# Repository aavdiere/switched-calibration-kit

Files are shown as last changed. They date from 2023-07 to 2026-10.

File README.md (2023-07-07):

# Switched Calibration Kit (SCal)
DIY calibration module that automatically switches between calibration standards.
The idea is to use of the shelf RF switches with simple SMD resistors, which can be characterized using a reference measurement of a VNA and then used as a standard.

This is a data based approach is bound to imperfections. The other way would be to make a model of the calibration kit and reference that instead of a measurement.
As it is quite difficult to create a model for the switches without knowing the exact layout, the data approach was preferred.
The SCal is characterised and measured on the same day to avoid temperature fluctuations as they will impact the validity of the reference measurement, temperature control should be added on future revisions.

The boards were manufactured using Aisler's [four layer boards](https://community.aisler.net/t/4-layer-hd-pcb-stackup/86) using the Panasonic Prepreg 1080 Type R-1551(W).
The traces were designed to be 50Ω according to Aisler's recommendations.

## First version - Simple, cheap, proof of concept
Calibration kit using Infineon BGS12PN10/BGS14PN10.
- 2 ports
- 50 Ohm path
- Open path
- Short path
- Through path
- 3dB attenuation path

## Board
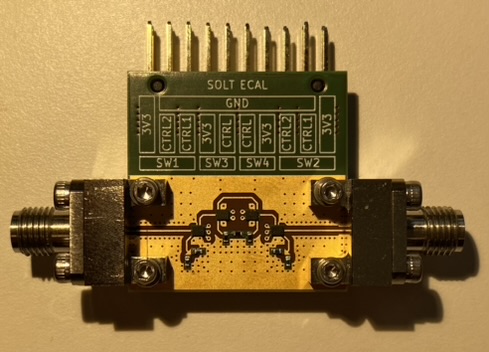
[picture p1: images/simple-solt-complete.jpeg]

*Full populated board. High-end K (2.92mm) connectors were used but are definitely not required. Screw on connectors were used to reduce the solder variability during initial measurements.*

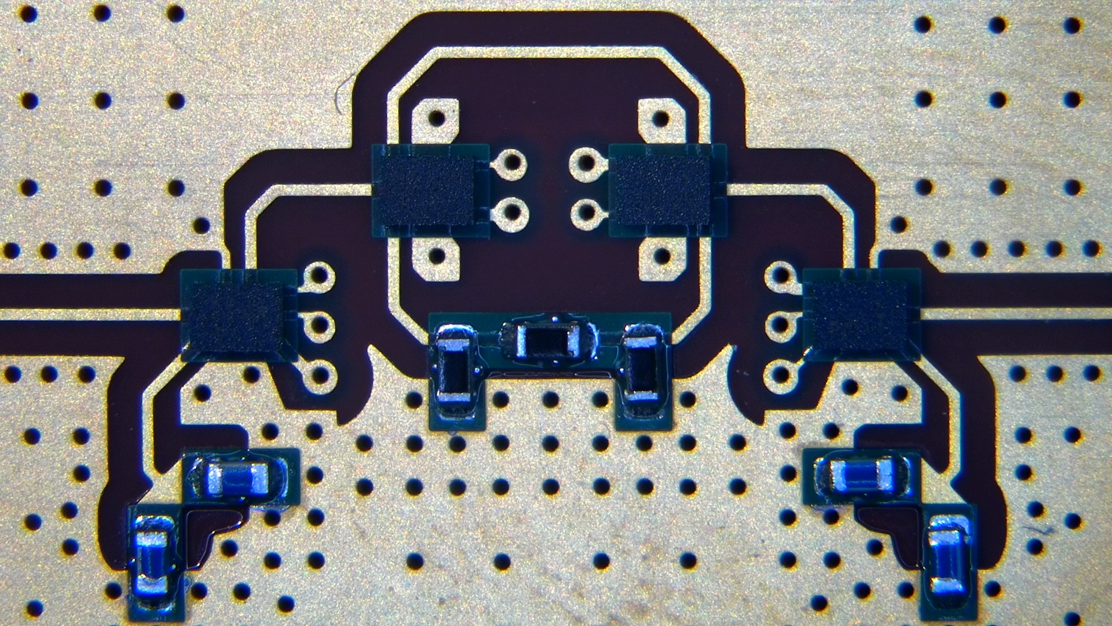
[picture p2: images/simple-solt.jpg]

*Close-up picture of the switches and standards. The 50Ω terminations are made using two paralell 100Ω resistors on the bottom left and right. The 3dB attenuator path can be seen in the middle, formed as a Π-network.*

## Measurement method
- Perform ECal using the Keysight N4691D calibration kit and the PNA-X
- Measure all of the standards of the custom ECal and save data with calibration applied (reference) and not applied
- Measure the Rosenberger RPC 2.92mm and save data with calibration applied (reference) and not applied
- Attach additional cable to existing cables
- Measure all of the standards of the custom ECal and save raw data (no calibration, raw)
- Measure the Rosenberger RPC 2.92mm and save raw data (no calibration, raw)
- Using Python and scikit-rf package, create a TwelveTerm network calibration using the measured reference ECal standards as ideals and the measured raw ECal standards as measured
- Use this error network to calibrate out the raw measurements of the Rosenberger calibration kit and compare them with the reference measurements

An additional measurement would be a repeatability test:
- Repeatedly measure short/open/load/through standards, making sure you unscrew and screw a different standard in and out each time
- Create the error network using all possible combinations of these measurements
- Measure the variance in error network parameters
- Do the same with the ECal (screw/unscrew after each run), the variance in parameters should be lower considering you don't need to unscrew/screw after measuring each standard

## Results
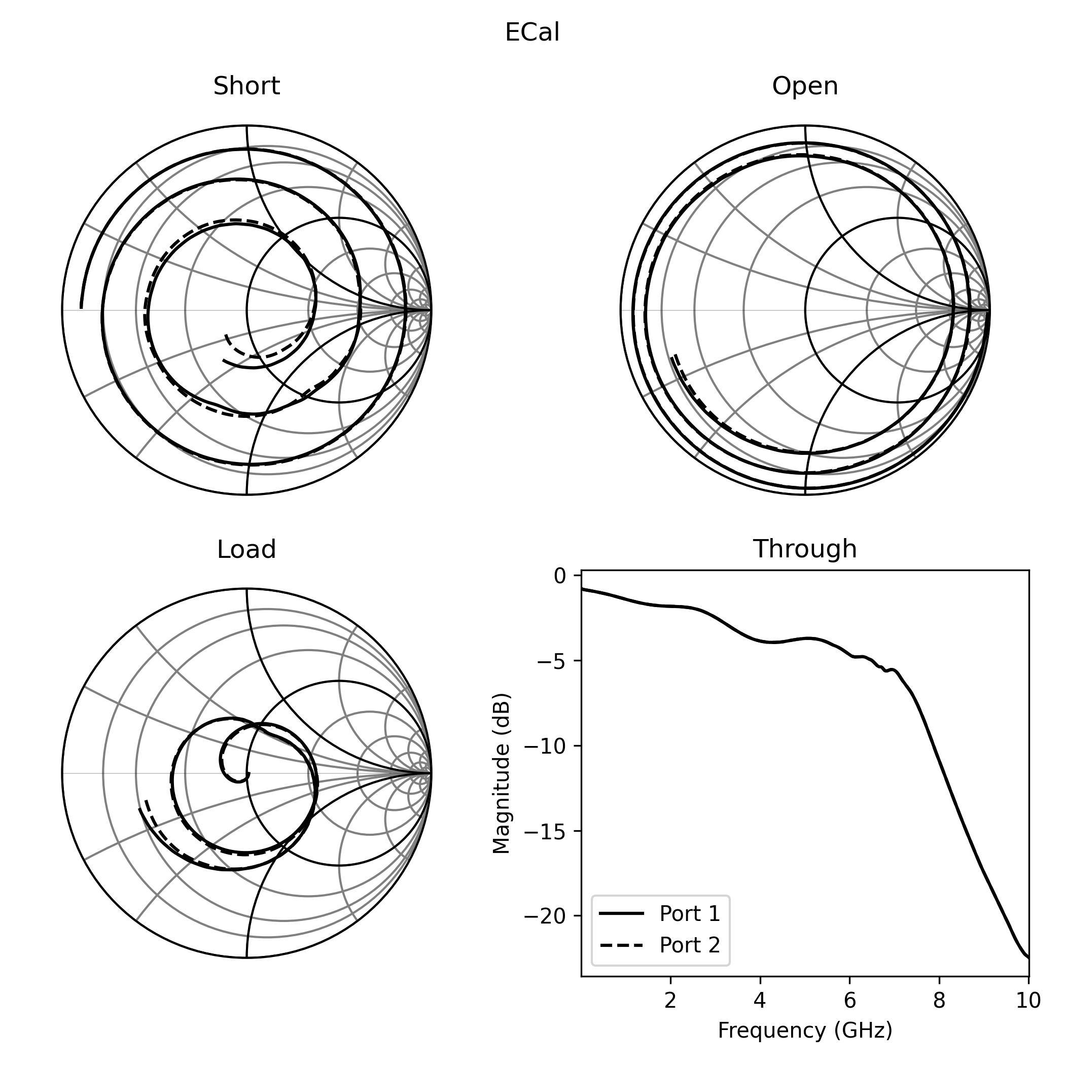
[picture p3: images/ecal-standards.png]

*Raw measurements of each of the standards. From the open and the short the port offset is visible as is the frequency dependent loss. The through result shows the bandwidth associated with the switches as well as the traces.*

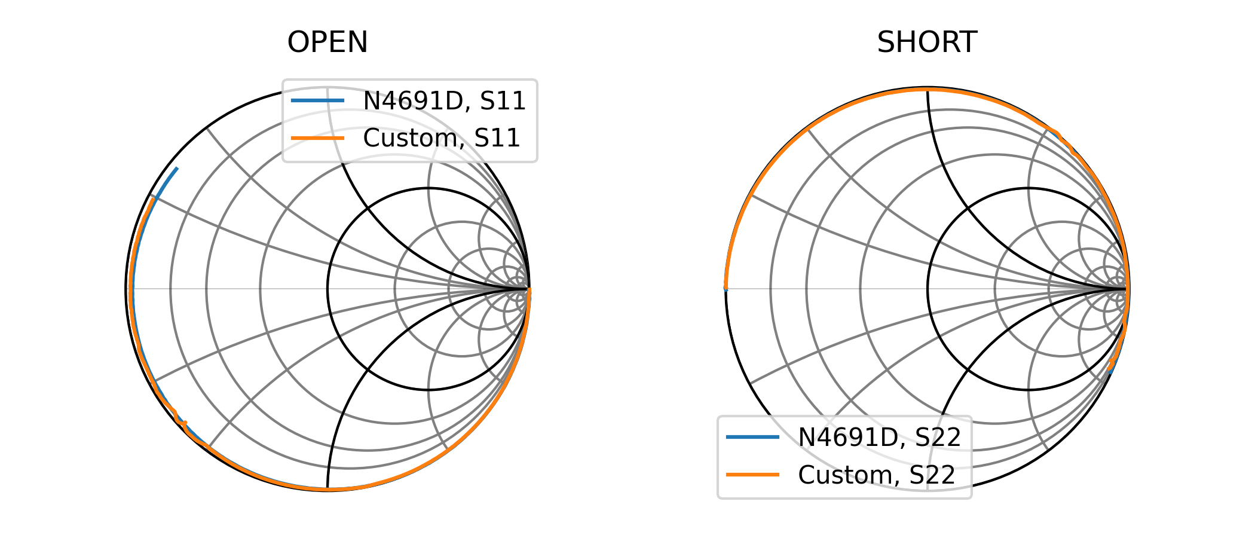
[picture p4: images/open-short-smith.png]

*Comparing the results from the SCal to the Keysight N4691D ECal, we can see comparible results, which look promising.*

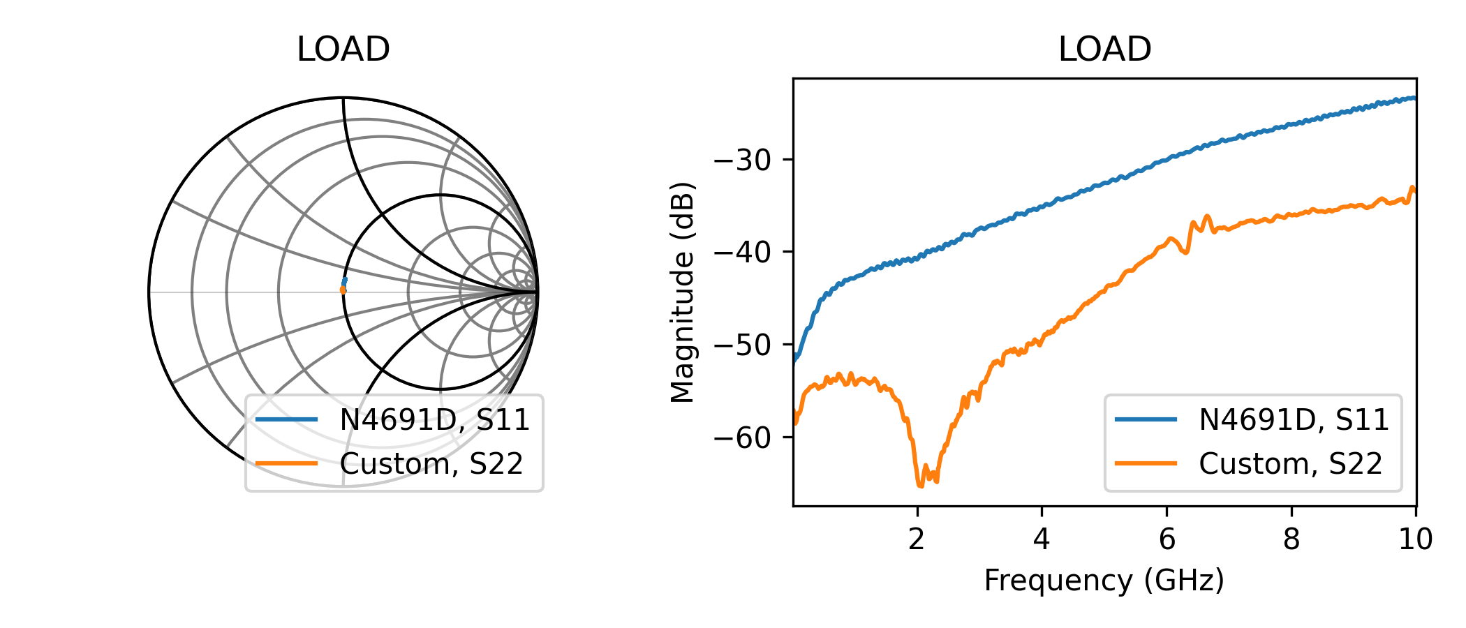
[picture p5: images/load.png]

*Differences in the measured load, somehow the SCal provides better results than the N4691D.*

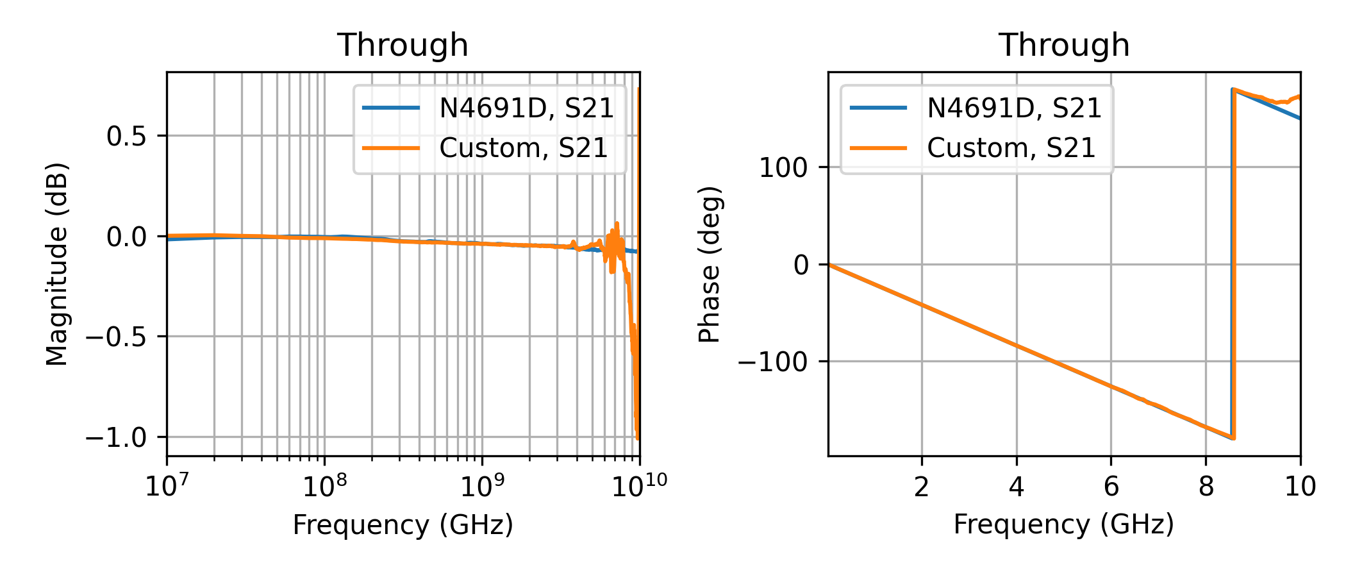
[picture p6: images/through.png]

*Here we can see the limitations of the measurements/switches. The measured through is nicely characterised up to around 3GHz, after which the SCal starts to deviate.*

## Remarks
The currently used silkscreen is confusing and prone to interconnection errors.
It might be a good idea to allow for rotational symmetry in the connector or to simply swap the legend around.

When looking at the load on the SCal, the S-parameters show that it starts of quite capacitive, which is odd.
This makes modelling it with typical methods difficult.
Maybe removing the whole top ground plane could fix that and only relying on microstrip lines.

The attenuator (not shown) doesn't have good performance, not even close.
Maybe using smaller resistors or a dedicated attenuator chip would be better.

The open and short standard should be located af far away from each other as possible as not to resonate.

The switches used have a minimum frequency in the datasheet.
This minimum frequency was ignored here and did not show up in the results.
However, if they are using PIN diodes to do the switching, the inductors used might not be good enough at lower frequencies, so watch out.

Overall the SCal has very nice results and could be usable for lower frequency measurements.

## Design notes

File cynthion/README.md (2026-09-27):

# Sniffing Keysight ECal USB interface using Cynthion

## Environment
To set-up the Python environment, you can use a version of conda.
```console
$ conda env create -f environment.yml
```

You can update a python environment from the [environment](environment.yml) file using
```console
$ conda env update -f environment.yml --prune
```

You can export conda environment to the [environment](environment.yml) file using
```console
$ conda export > environment.yml
```

## ECal states
https://documentation.help/SNP-M937xA/documentation.pdf

```python
set_state(device, 42)  # thru
set_state(device, 40)  # confidence
set_state(device, 36)  # open (a)
set_state(device, 33)  # open (b)
set_state(device, 39)  # short (a)
set_state(device, 45)  # short (b)
set_state(device, 37)  # load
set_state(device, 53)  # offset short
set_state(device, 5)  # impedance 5 (offset open)
set_state(device, 21)  # impedance 6 (offset short)
set_state(device, 38)  # impedance 7 (offset short)
```

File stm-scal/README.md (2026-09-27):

# STM Template

Template project tailored with use with STM32 microcontroller and Visual Studio Code.
The default is made for stm32l4 with JLink programmer and should be modified accordingly.

## Prerequisites

You need to have the following installed and properly setup. Ensure that they are available in your path.

- [GNU ARM Embedded tools](https://developer.arm.com/downloads/-/gnu-rm)
- [GNU Make](https://www.gnu.org/software/make/)
- Linker script for the MCU, probably has to be created manually, example can be found in the [libopencm3 example repository](https://github.com/libopencm3/libopencm3-examples)

### When using Visual Studio Code

You'll want to install some extensions to make development smoother

- `C/C++`
- `Cortex-Debug`
- `CMake Tools`

## Repo setup

Change the microcontroller identifier in the [Makefile](Makefile) and, when using Visual Studio Code, change it in [settings.json](.vscode/settings.json)

```bash
# Initialise the submodules (libopencm3)
git submodule init
git submodule update

# Build libopencm3
make -j8 -C vendor/libopencm3

# Build the main application firmware
make
```

## Debuggers

### J-Link

The YouTube series makes use of J-Link debugger hardware and JLinkGDBServer for integrating with VS Code's debug functionality.

You can use the "JLink: Debug Application" and "JLink: Attach to active" VSCode tasks to debug your built binaries.

### ST-Link

ST-Link is alternative debugger that you can use if you don't have a JLink debugger.

It's recommended that you install the [ST-Link drivers](https://www.st.com/en/development-tools/stsw-link009.html).

You'll also need to install the [open source ST-Link debugging tools](https://github.com/stlink-org/stlink). The primary application you'll need from that tool-set is *stutil*. Verify that *stutil* is available in your path before attempting to use the VSCode ST-Link debugging tasks.

Once your drivers and debugging tools are installed, you can use the "ST-Link: Debug Application" and "ST-Link: Attach active" VSCode tasks to debug your firmware over ST-Link.

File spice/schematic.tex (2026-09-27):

\documentclass[border=10pt]{standalone}
\usepackage[siunitx, americanvoltages, americancurrents]{circuitikz}
\ctikzset{resistors/scale=0.8, capacitors/scale=0.8}

\begin{document}
\begin{circuitikz}[scale=1.0, every node/.style={font=\footnotesize}]

% ================= Op-amp (declared first so its anchors can be used below) =================
\node[op amp] (opamp) at (6,7) {};

% ================= PI feedback rail (top row, y=11) =================
\draw (-2,11) to[V, l_=$V_{set}$=1.2V] ++(0,-1.8) node[ground]{};
\draw (-2,11) to[R, l=$R_{in}$=10k] (5,11) coordinate (nsum);
\draw (nsum) to[R, l=$R_{fb}$=100k] (7,11)
             to[C, l=$C_{int}$=3000$\mu$F] (8,11) coordinate (ngtop);
\draw (nsum) |- (opamp.-);

% ================= NTC sense divider =================
\draw (2,9.3) to[V, l=$V_{in}$=3.3V] (2,6.5) node[ground]{};
\draw (2,9.3) -- (2,9.6) -- (3.5,9.6)
      to[R, l=$R_s$=10k] (3.5,8);
\node[circ, label=right:$n_{temp}$] at (3.5,8) {};
\draw (3.5,8) to[R, l_=$R_{ntc}(T)$] (3.5,6.5) node[ground]{};
\draw (3.5,8) -- (4.5,8) |- (opamp.+);

% ================= Op-amp wiring =================
\draw (opamp.out) -- (8,7) coordinate (ngate);
\node[circ, label=below:$n_{gate}$] at (ngate) {};
\draw (opamp.up)   -- ++(0,0.4) node[above]{$n_{5v}$};
\draw (opamp.down) -- ++(0,-0.4) node[below]{GND};
\draw (ngtop) -- (ngate);

% ================= Heater switch =================
\draw (12,9.3) to[V, l=$V_{5v}$=5V] (12,7.4);
\node[circ] at (12,7.4) {};
\draw (12,7.4) -- (12.8,7.4);
\node[nmos] (M1) at (12.8,6.4) {};
\draw (12.8,7.4) -- (M1.D);
\draw (ngate) -- ++(0,-3.0) -| (M1.G);
\draw (M1.S) -- ++(0,-0.5) coordinate (nsrc);
\node[circ, label=right:$n_{source}$] at (nsrc) {};
\draw (nsrc) to[R, l_=$R_{heat}$=4$\Omega$] ++(0,-1.8) node[ground]{};

% ================= Thermal coupling (dashed) =================
\draw[dashed, ->, thick] (12.8,3.1) -- (12.8,0.8) -- (3.5,0.8) -- (3.5,6.3);
\node[font=\scriptsize, align=center] at (7,2.2)
      {thermal link: heater power $\to$ node ``temp'' (Celsius)\\
       $R_{th}$=8 C/W, $C_{th}$=39.9 J/C, ambient=22C\\
       $R_{ntc}$ value driven by resulting temp};

\end{circuitikz}
\end{document}

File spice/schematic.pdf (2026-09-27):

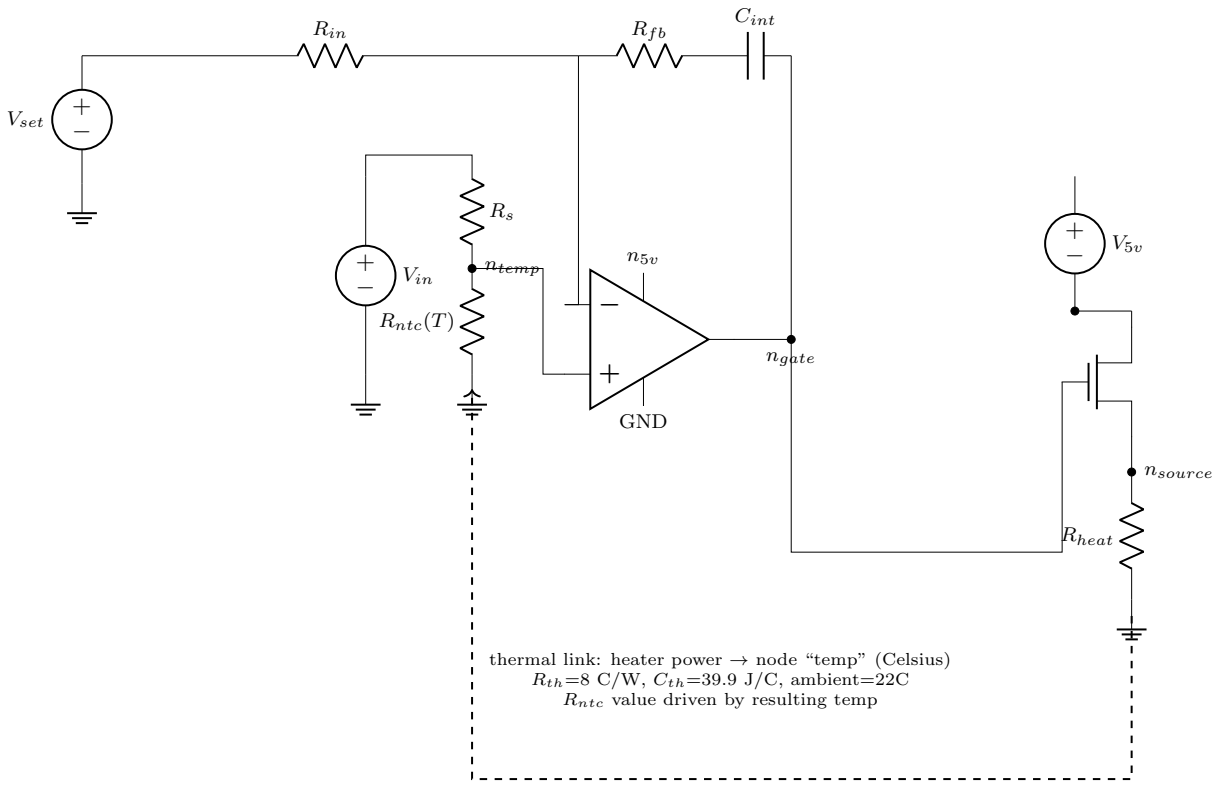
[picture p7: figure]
+ Vset; Rin; Cint; Vin; ntemp; Rntc(T); ngate; GND; nsource; Rheat; Rth=8 C/W, Cth=39.9 J/C, ambient=22C Rntc value driven by resulting temp

thermal link: heater power → node “temp” (Celsius)

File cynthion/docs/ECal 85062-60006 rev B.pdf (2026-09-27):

## ECal kit 85062-60006

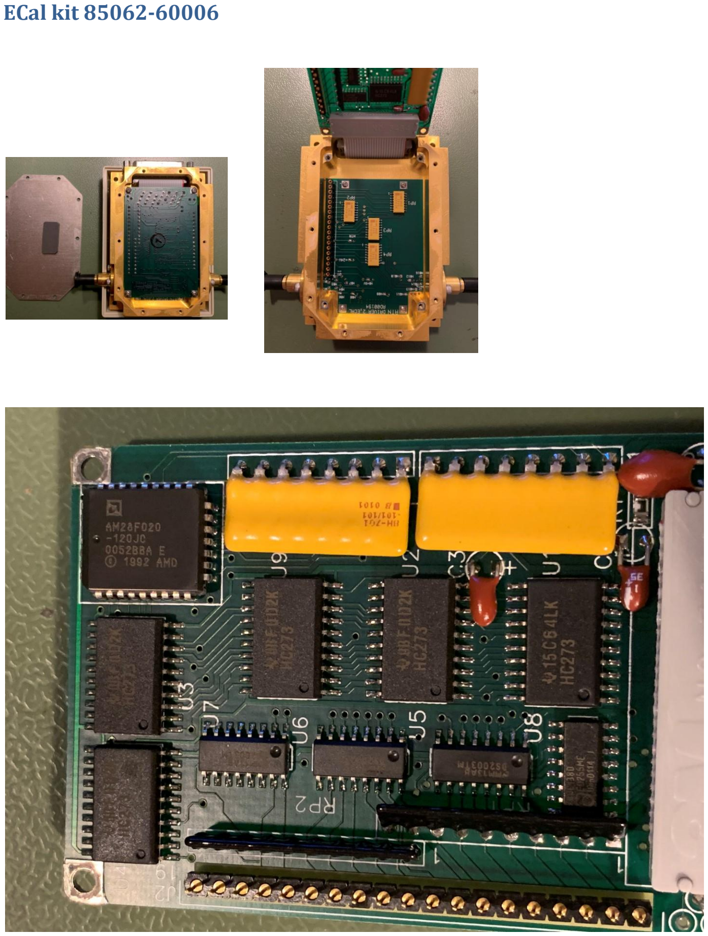
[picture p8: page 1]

## Pin connections DSUB-25

Table. Pinout DSUB-25 on 85062-6006 ECal kit. Last two columns not relevant for the kit, but can be used when building an Arduino adapter.

Pin | Input/Output (to/from 85062) | Description | Colour on cables | Arduino pin
1 | Power | J2-19, Analog +24 V *
14 | Power | J2-18, Analog GND***
2 | Power | Digital GND***, connected to DSUB-15
15 | Power | Digital GND***, connected to DSUB-2 | Black | GND
3 | Power | VCC +5 V*, U8-6 (Mux E3) | Red | +5 V
16 | Power | J2-17 Analog +5 V*
4 | I | Flash pin 1 VPP
17 | I | Analog -12 (negative) V* Jumper site 1 ****
5 | O | Short to DSUB-18 “Detect connect”
18 | O | Short to DSUB-5 “Detect connect”
6 | I | D-latch-1 MR’ = CLEAR’ | White | A2
19 | I | Flash-31 WE’ | Orange | A1
7 | I | Flash-24 OE’, HOLD HIGH when flash is not selected! | Orange | A0
20 | I | U8-4,5 E1’, E2’, Mux Enable | Green | D13
8 | I | U8-3 A2 Mux address | Green | D12
21 | I | U8-2 A1 Mux address | Green | D11
9 | I | U8-1 A0 Mux address | Green | D10
22 | I/O** | D-latch-D7, Flash-D7 | White | D9
10 | I/O** | D-latch-D6, Flash-D6 | White | D8
23 | I/O** | D-latch-D5, Flash-D5 | White | D7
11 | I/O** | D-latch-D4, Flash-D4 | White | D6
24 | I/O** | D-latch-D3, Flash-D3 | White | D5
12 | I/O** | D-latch-D2, Flash-D2 | White | D4
25 | I/O** | D-latch-D1, Flash-D1 | White | D3
13 | I/O** | D-latch-D0, Flash-D0 | White | D2
* Note. DSUB 1, 3, 16, 17. These are only fed from 85097 when DSUB-5 and -18 are connected to each other (max voltage drop 2 V, unloaded voltage drop between these pins is 12 V).

**Note. To protect from driving a pin that may be configured for output, a 10 kΩ resistor can be put in series without affecting function.

***Note. Digital and analog GND should be connected externally as they are so in the controller 85097. Otherwise current for Analog 5 V will not be able to flow properly.

****Note. On the board where the DSUB is connected, there is a ‘jumper site’ – small area with three holes labeled 1, 2 and 3. In this unit, 2 and 3 connected, 1 not connected. This site appears to be used for passing -12 V in (at least) low frequency units.

## Chips

### U8 – 74HC138 3-8 MUX

### U1, U2, U9, U3, U4 – 74HC238 D-latch. All sharing D0-D7 and MR’ connected to DSUB-6

U5, U6, U7 DS2003, Darlington drivers ending up in J2. Fed by D-latches.

### Flash AM28F020, 8 MBit Flash, 256kx8

U8 MUX connection to other ICs. Chosen address sets corresponding pin LOW when U8 is enabled

### (otherwise all pins are HIGH)

MUX Address | IC
0 | U1 D-Latch (Clock pos edge) -> U5:1-7, U6:1 -> J2:1-8
1 | U2 D-Latch (Clock pos edge) -> U6:2-7, U7:1-2 -> J2:9-16
2 | U3 D-Latch (Clock pos edge) Flash A0-A7
3 | U4 D-Latch (Clock pos edge) Flash A8-A15
4 | U9 D-Latch (Clock pos edge) Flash A16-A17 (Q2 – Q7 unused)
5
6
7 | Flash-22 – CE’

## D-Latch

WRITING to D-Latch is done by selecting one chip (this clock pin goes low), activate data bus and deselect the chip (clock pin goes high). Thus, writing to D-latches occurs when deselecting the chip!

## Sequence to RESET ALL D-Latches:

DSUB20 HIGH | U8-4,5 E1’, E2’ (mux disabled, all pins high)
DSUB6 LOW | All D-Latch CLR’ activated
DSUB6 HIGH | All D-Latch CLR’ deactivated

## Sequence to write certain D-Latch:

DSUB6 HIGH | All D-Latch CLR’ deactivated
DSUB20 HIGH | U8-4,5 E1’, E2’ (MUX disabled, all pins high)

### DSUB 9/21/8 ADDRESS U8 A0-A2, select MUX pin address

DSUB20 LOW | U8-4,5 E1’, E2’ (MUX enabled, addressed pin low)
DSUB D-Latch D0-D7 | DATA set data on pins 22, 10, 23, 11, 24, 12, 25, 13
DSUB20 HIGH | U8-4,5 E1’, E2’ (MUX disabled, all pins high, DATA is clocked into D-Latch)

## Flash

Flash CE’ is active low and will thus activate when selected.

### CAUTION: When activated, it MAY OUTPUT VOLTAGE ON DSUB D-Latch D0-D7/Flash D0-D7! Thus

use a series 10 kΩ resistor on each line.

Flash: CE’ – controls power within the device. Keep low.

Flash: OE’ – Output enable if pin is LOW. If pin is high, data pins are three state! Set this pin HIGH

### when programming D-Latches!

With OE’ LOW, Flash will output the data stored in location specified by address stored in U3, U4 and U9

WE’ should be held HIGH, but likely not an issue as long as VPP isn’t pulled too high...

## Pins on J2 (controlling RF circuitry)

Programming pins on J2 1-16. Setting one of the bits in the D-Latch registers HIGH will pull the corresponding J2 pin set (LOW). Voltage on J2 pins are approx 4.5 V when set (LOW) and 21.8 when not set (HIGH). Current consumption on 24 V seems not affected by the pins being HIGH or LOW.

On 5 V, current draw is depending on any bit being high or not. For all bits 0, current draw is 0, any bit set, current draw is approx 340 uA if GNDs are connected by 10 kOhms.

## Current draw

Note that 24 V seems to draw substantial amounts of current. This is related to the internal heater of the ECal kit. By setting current limit to 300 mA, it takes approximately 30 minutes to reach a steady state where current decreases to approximately 80 mA.

The +5 V analog draws approximately 40 mA per activated switch (i. e, some 120 mA in normal configuration like 0x8003, 0x4003 etc).

### More thorough data from W. Knowles:

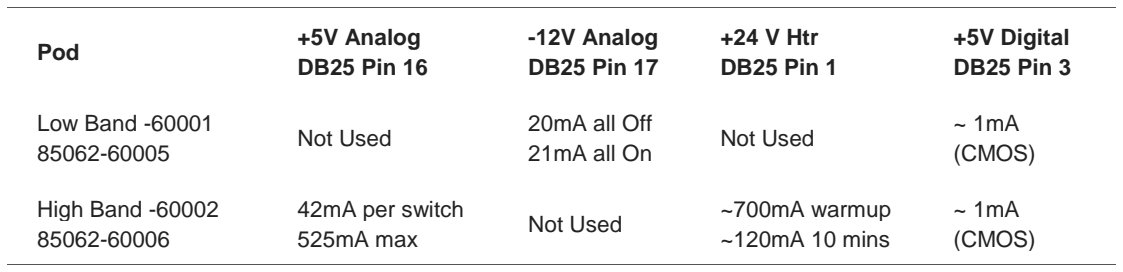
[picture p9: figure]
Pod; +5V Analog; DB25 Pin 16; -12V Analog DB25 Pin 17; +24 V Htr DB25 Pin 1; +5V Digital DB25 Pin 3; Low Band -60001; Not Used; 20mA all Off; 21mA all On; (CMOS); High Band -60002 85062-60006; 42mA per switch; 525mA max; ~700mA warmup; ~120mA 10 mins; ~ 1mA (CMOS)

## Flash content HP85062-60006 ECAL kit

0x0000 – 0x0063 Original info
0x0064 – | Serial no
0x0070 - | connector info
0x0084 - | possible update info, including cal site?
0x00B8 – | Revision?
0x00CC – | start and stop frequency as doubles
| 0x41cd cd65 0000 0000 –> 1 000 000 000
| 0x4218 ae17 a400 0000 –> 26 500 000 000
0x00DC – 0001 -> 256, number of points? 0x00DE – 2C01 -> 300, warm up time in seconds?
0x00E0 – | Frequency step as double
| 0x4197 d784 0000 0000 -> 100 000 000
0x00E8 – | Address 0x0001 8000?
0x00EC – 5595 -> 38229, number of bytes for all datasets?
0x00F0 – | Part no.
00000000: 4850 3835 3036 3043 2045 4341 4c00 85c0 | HP85060C ECAL...
00000010: 7c25 e87f 6400 4e6f 7620 3238 2031 3939 | |%..d.Nov 28 199
00000020: 3400 ffff ffff ffff ffff ffff ffff ffff | 4 |
00000030: ffff ffff ffff ffff ffff ffff ffff ffff | |
00000040: ffff ffff ffff ffff ffff ffff ffff ffff | |
00000050: ffff ffff ffff ffff ffff ffff ffff ffff | |
00000060: ffff ffff | 3031 3233 3400 31c0 50e8 8808 | ....01234.1.P...
00000070: | 3335 4633 3546 204d 5731 | 00c4 0456 e8fb | 35F35F MW1...V..
00000080: 0883 c402 | 3137 204d 6179 2032 3031 3100 | ....17 May 2011.
00000090: | 4147 494c 454e 542f 4d54 4100 b8f8 6aeb | AGILENT/MTA...j.
000000a0: 9383 3e94 0600 741e a182 0683 c041 a298 | ..>...t......A..
000000b0: 06c6 069b 0600 b804 | 3031 2e30 3000 | 00c6 | ........01.00...
000000c0: 08eb 29e9 9a00 8dbe 4cff 837e | 0000 0000 | ..).....L..~....
000000d0: | 65cd cd41 | 0000 00a4 17ae 1842 | 0001 2c01 | e..A.......B..,.
000000e0: | 0000 0000 84d7 9741 | 0080 0100 | 5595 0000 | .......A....U...
000000f0: | 3835 3036 322d 3630 3030 3600 | 0075 03e9 | 85062-60006..u..
00000100: 39ff c706 0000 0002 3130 3838 00e5 33c7 | 9.......1088..3.
00000110: 0686 0601 ffff ffff ffff ffff ffff ffff | |
00000120: ffff ffff ffff ffff ffff ffff ffff ffff | |
00000130: ffff ffff ffff ffff ffff ffff ffff ffff | |
00000140: ffff ffff ffff ffff ffff ffff ffff ffff | |
00000150: ffff ffff ffff ffff ffff ffff ffff ffff | |
00000160: ffff ffff ffff ffff ffff ffff ffff ffff | |
00000170: ffff ffff ffff ffff ffff ffff ffff ffff | |
00000180: ffff ffff ffff ffff ffff ffff ffff ffff | |

0x0190 – 0x1CD Header info for cal files.

Static structure beginning with one frequency list and then datasets of S-parameters. Prior to each set of S-parameters is a list of Short (16 bit) words about how the ECal shall be configured – see below.
Header content:

Frequency: No of entries (Short), start location (Long)

Corr values: No of config words for Ecal (Short), No of entries per set (short), No of sets (short), Start location config (Long), Start location first data set (Long)

00000190: 0001 f401 0000 0d00 0001 0d00 f409 0000 | |
000001a0: 0e0a 0000 0d00 0001 0d00 0e72 0000 2872 | | r..(r
000001b0: 0000 0100 0001 0400 28da 0000 2ada 0000 | ........(...*...
000001c0: 0100 0001 0400 2afa 0000 2cfa 0000 ffff | ......*...,.....
000001d0: ffff ffff ffff ffff ffff ffff ffff ffff | |
000001e0: ffff ffff ffff ffff ffff ffff ffff ffff | |

Frequency.
Frequency data starts at 0x000001F4 and contains 0x0100 entries. Data for frequency is stored in Double format (64 bit) in Hz. In this case, frequencies at 1.0, 1.1, ..., 26.5 GHz
000001f0: ffff ffff 0000 0000 65cd cd41 0000 00c0 | ........e..A....
00000200: 2a64 d041 0000 0000 a3e1 d141 0000 0040 | *d.A.......A...@

Corr values.
Following in the header are four areas of datasets (all containing more than one set of S-parameters). Config list contains Short (16 bit) config words to set the ECal to. Data is stored as Real, Imag, Real, Imag,... where each value is stored as float (32 bit)
No of config | Set length | No of sets | Config start | Set start
0x0D | 0x100 | 0x0D | 000009F4 | 00000A0E
0x0D | 0x100 | 0x0D | 0000720E | 00007228
0x01 | 0x100 | 0x04 | 0000DA28 | 0000DA2A
0x01 | 0x100 | 0x04 | 0000FA2A | 0000FA2C

### Dataset 1 0x09F4

13 config words, 13 datasets. One S-parameter per config.
Config # | Setting | Config # | Setting
0 | 8003 | 7 | 0083
1 | 4003 | 8 | 0043
2 | 2003 | 9 | 0023
3 | 1003 | 10 | 0013
4 | 0803 | 11 | 000B
5 | 0403 | 12 | 0007
6 | 0103

000009f0: 17ae 1842 0380 0340 0320 0310 0308 0304 | ...B...@. ......
00000a00: 0301 8300 4300 2300 1300 0b00 0700 0078 | ....C.#........x
00000a10: d2be 004c 533f 0014 8bbe 0054 613f 0050 | ...LS?.....Ta?.P
00000a20: 04be 0030 693f 0000 513c 0026 6b3f 0040 | ...0i?..Q<.&k?.@
00000a30: 1b3e 0080 673f 00d0 903e 00ba 5e3f 0074 | .>..g?...>..^?.t
00000a40: d03e 00a0 513f 0080 053f 000c 403f 00be | .>..Q?...?..@?..
00000a50: 1f3f 009e 2a3f 0066 363f 00f0 113f 0068 | .?..*?.f6?...?.h

### Dataset 2 0x720E

13 config words, 13 datasets. One S-parameter per config.
Config # | Setting | Config # | Setting
0 | C001 | 7 | C100
1 | C002 | 8 | C200
2 | C004 | 9 | C400
3 | C008 | 10 | C800
4 | C010 | 11 | D000
5 | C020 | 12 | E000
6 | C080
00007200: c93e 0008 d5bd 0088 af3e 00d8 76be 01c0 | .>.......>..v...
00007210: 02c0 04c0 08c0 10c0 20c0 80c0 00c1 00c2 | |
00007220: 00c4 00c8 00d0 00e0 0014 d0be 00de 543f

### Dataset 3 0xDA28

Single config, 4 datasets (all four S-parameters). DA28: 0x0000

0000da20: 00b2 b03e 0058 6ebe 0000 0070 943d 0018 | ...>.Xn....p.=..
0000da30: 3fbe 00c0 783c 00be 44be 0078 17bd 003e | ?...x<..D..x...>

### Dataset 4 0xFA2A

Single config, 4 datasets (all four S-parameters).
FA2A: 0x0200
0000fa20: a6bd 00fc 4d3d 00f6 b1bd 0002 000c 9c3e | ....M=.........>
0000fa30: 00bc 533f 0094 fc3e 00b6 3a3f 004c 263f | ..S?...>..:?.L&?

Length of the datasets (note: first location is also used for data): A0E – 720D : 26624, 13*256*2*4 = 26624...
722A – DA27: 26624...
DA2C – FA29: 8192
Finally:
0xFA2B + 0x2000 = 112AB. Data content in flash ends at 0x112AB.

### Useful or comments? Please drop me a line at testjarfalla63@gmail.com

### /Staffan

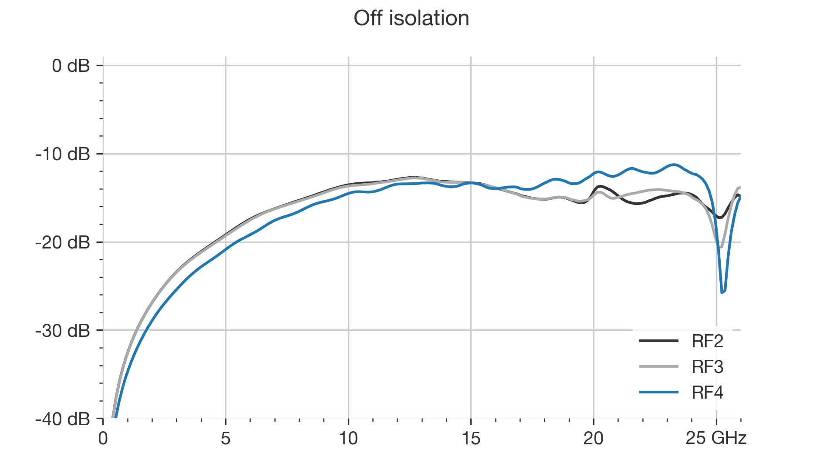
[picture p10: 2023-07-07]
images/off-isolation.png

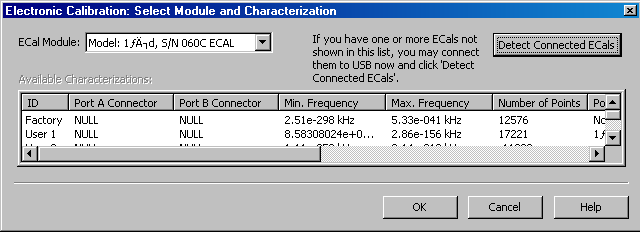
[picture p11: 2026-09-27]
cynthion/docs/Reverse-engineering a VNA ECal Interface With Cynthion - Great Scott Gadgets_files/ecal-garbled.png

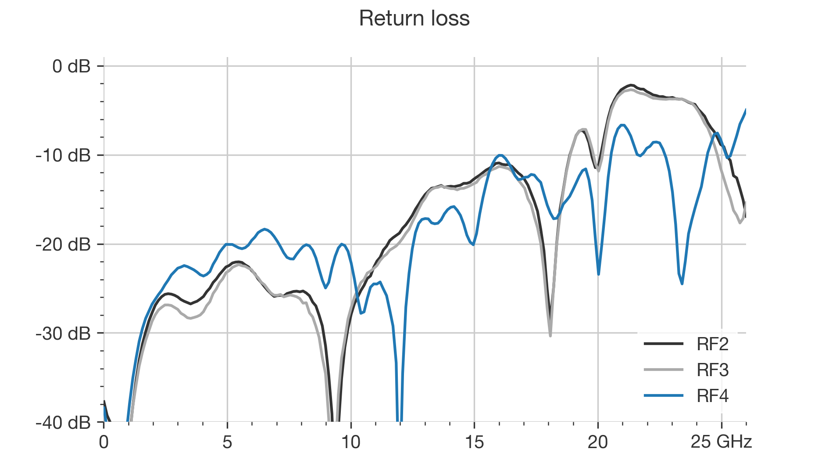
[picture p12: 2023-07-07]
images/return-loss.png

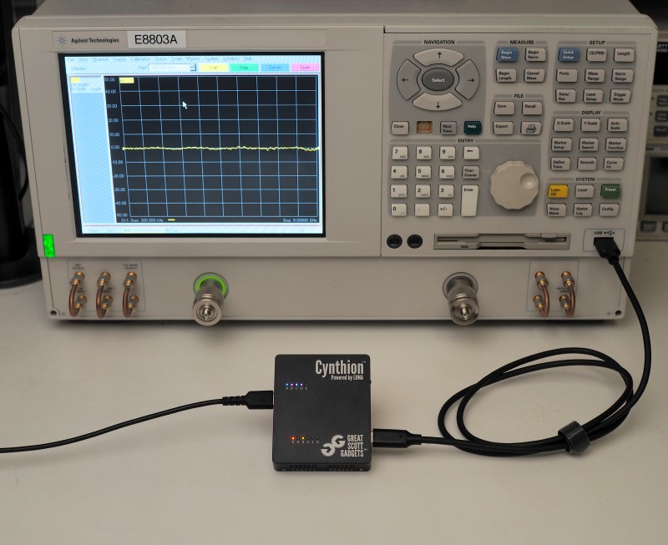
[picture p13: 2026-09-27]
cynthion/docs/Reverse-engineering a VNA ECal Interface With Cynthion - Great Scott Gadgets_files/ecal-vna.jpg

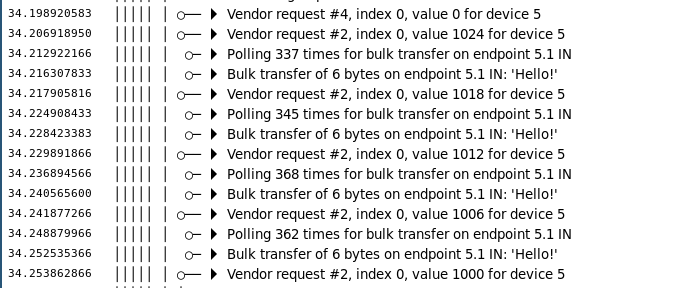
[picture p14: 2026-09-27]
cynthion/docs/Reverse-engineering a VNA ECal Interface With Cynthion - Great Scott Gadgets_files/ecal-packets.png

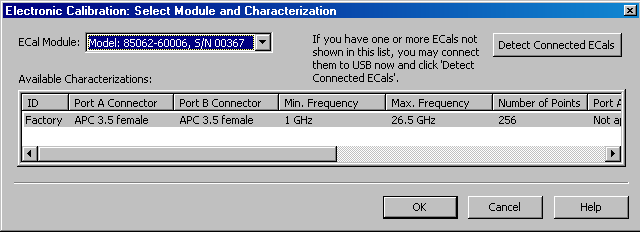
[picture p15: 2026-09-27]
cynthion/docs/Reverse-engineering a VNA ECal Interface With Cynthion - Great Scott Gadgets_files/ecal-correct.png

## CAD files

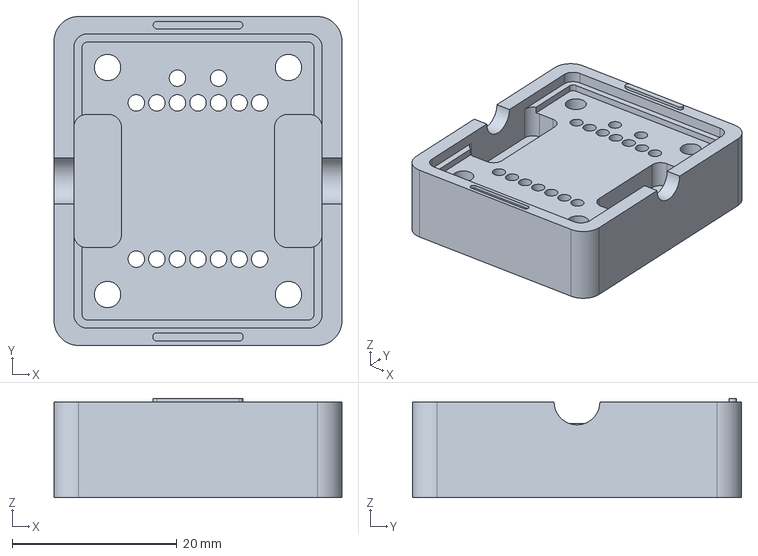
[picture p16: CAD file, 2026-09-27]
CAD/assembly-Assemblycase_bottom.step
35.0 x 40.0 x 12.1 mm

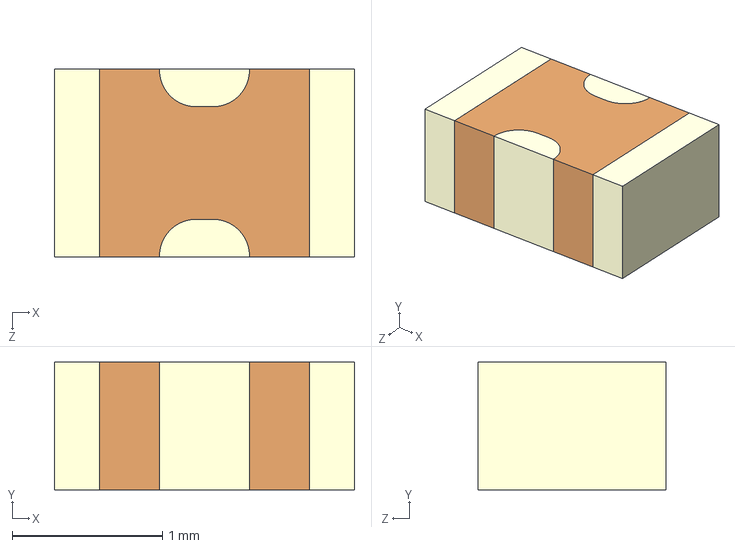
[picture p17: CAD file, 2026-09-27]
KiCad/ecal_controller/NFM21PC104R1E3D.stp
2.00 x 0.85 x 1.25 mm

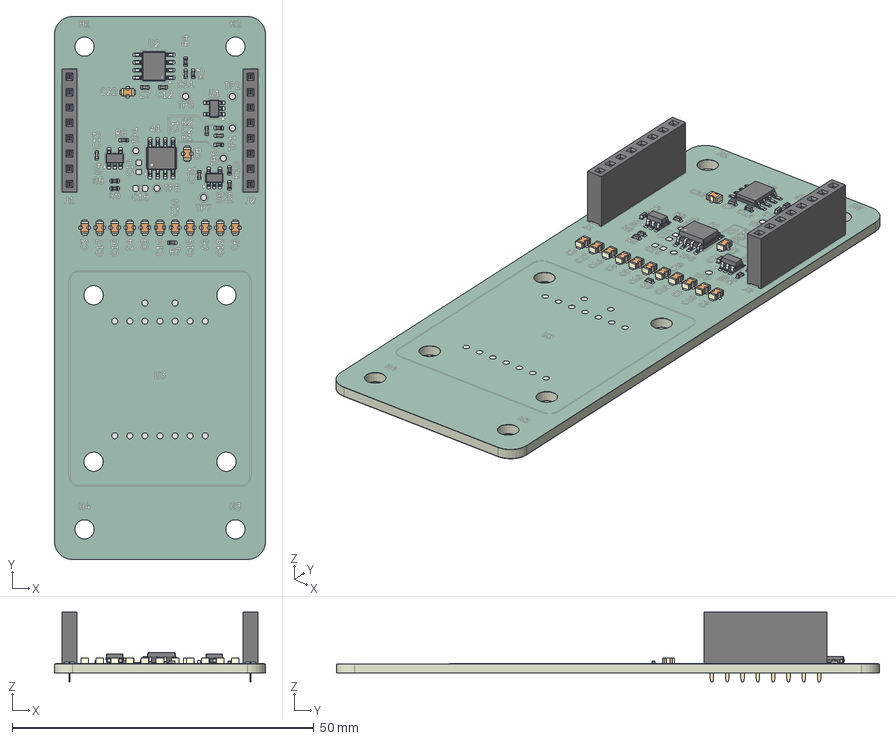
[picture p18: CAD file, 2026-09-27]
KiCad/ecal_heater_control/ecal_heater_control.step
35.0 x 90.0 x 11.6 mm
SOT-23-5 x 3
HTSOP-8-1EP_3.9x4.9mm_P1.27mm_EP2.4x3.2mm
R_0402_1005Metric x 10
NFM21PC104R1E3D x 13
SOIC-8_3.9x4.9mm_P1.27mm
C_0402_1005Metric x 7
PinSocket_1x08_P2.54mm_Vertical x 2
ecal_heater_control_copper
ecal_heater_control_pad
ecal_heater_control_via
ecal_heater_control_silkscreen
ecal_heater_control_soldermask x 2
ecal_heater_control_PCB

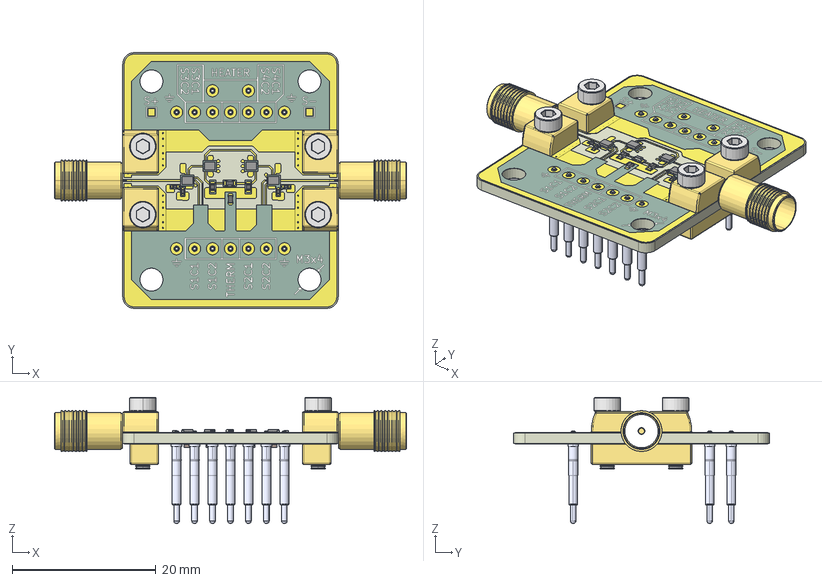
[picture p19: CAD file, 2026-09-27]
KiCad/ecal_simple_solt/ecal_simple_solt.step
49.0 x 35.6 x 17.6 mm
All x 2
R_0402_1005Metric x 4
BGS14PN10E6327XTSA1 x 4
R_0201_0603Metric x 4
C_0402_1005Metric x 4
Same_Sky_CPG-01-TH-B x 16
ecal_simple_solt_copper
ecal_simple_solt_silkscreen x 2
ecal_simple_solt_soldermask x 2
ecal_simple_solt_PCB

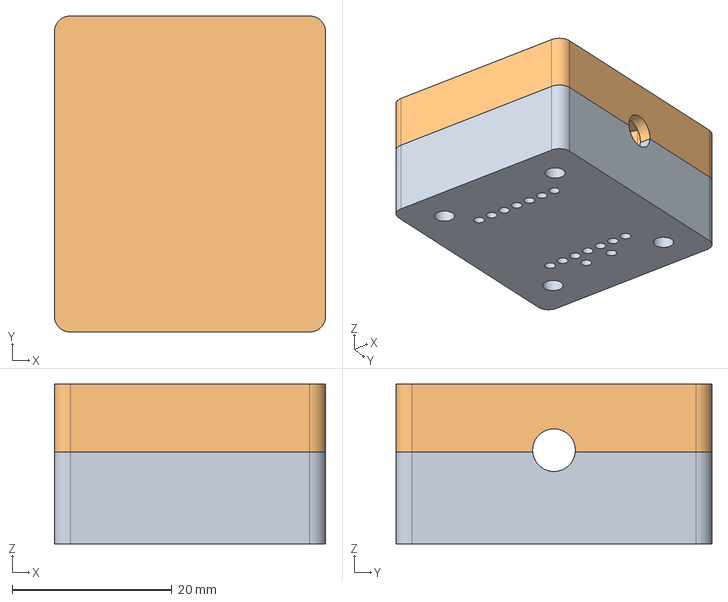
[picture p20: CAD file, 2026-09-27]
CAD/PCB.FCStd
34.0 x 39.6 x 20.0 mm
bottom
top

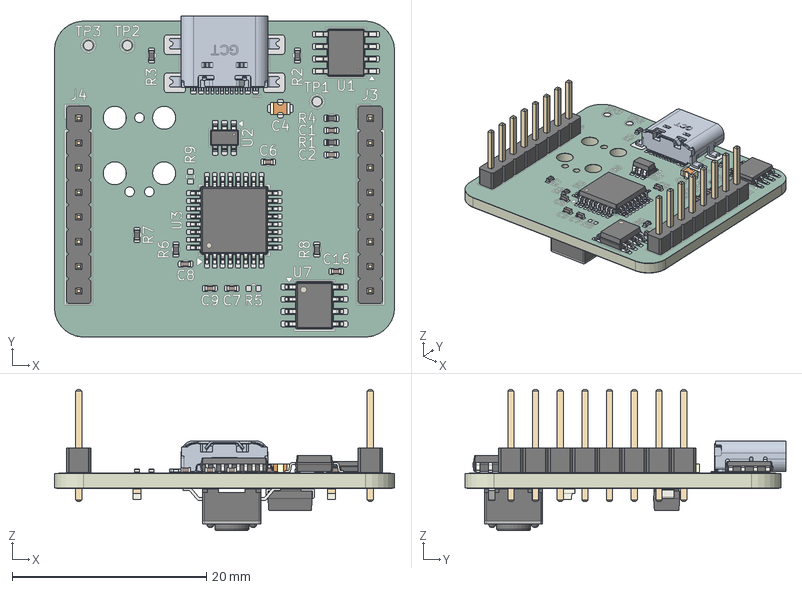
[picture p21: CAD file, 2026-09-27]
KiCad/ecal_controller/ecal_controller.step
35.0 x 33.0 x 14.5 mm
C_0402_1005Metric x 7
R_0402_1005Metric x 7
PinHeader_1x08_P254mm_Vertical x 2
SOT-23-6
LQFP-32_7x7mm_P0.8mm
HTSOP-8-1EP_3.9x4.9mm_P1.27mm_EP2.4x3.2mm
SOIC-8_3.9x4.9mm_P1.27mm
NFM21PC104R1E3D
SW_Push_1P1T_NO_E-Switch_TL3301NxxxxxG
LED_0603_1608Metric x 2
D_SMA
ecal_controller_copper
ecal_controller_pad
ecal_controller_via
ecal_controller_silkscreen x 2
ecal_controller_soldermask x 2
ecal_controller_PCB

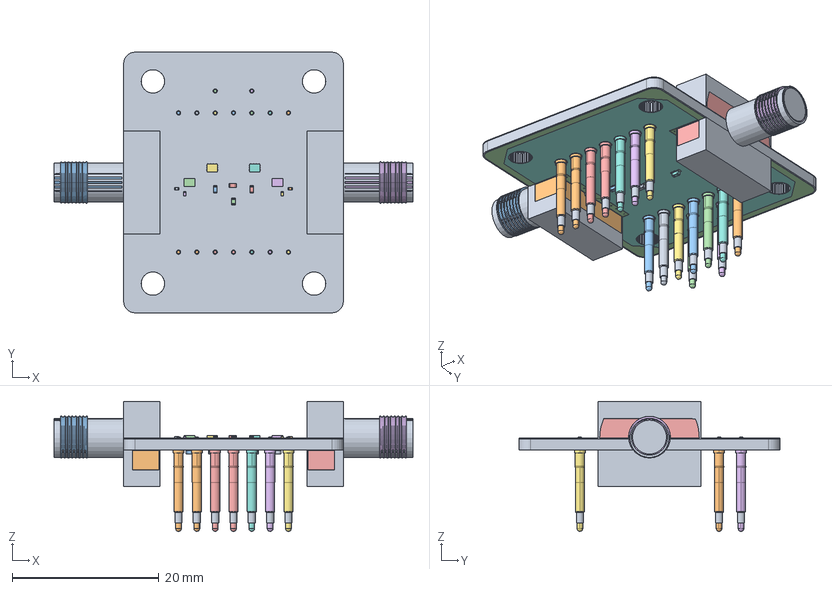
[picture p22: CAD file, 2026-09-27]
CAD/scal.FCStd
49.0 x 35.6 x 17.8 mm
abstract
All
All001
R_0402_1005Metric
R_0402_1005Metric002
BGS14PN10E6327XTSA1
BGS14PN10E6327XTSA001
BGS14PN10E6327XTSA002
R_0201_0603Metric
R_0201_0603Metric002
R_0402_1005Metric004
BGS14PN10E6327XTSA003
R_0402_1005Metric006
R_0201_0603Metric004
R_0201_0603Metric006
C_0402_1005Metric
Same_Sky_CPG-01-TH-B
Same_Sky_CPG-01-TH-B001
C_0402_1005Metric002
Same_Sky_CPG-01-TH-B002
Same_Sky_CPG-01-TH-B003
Same_Sky_CPG-01-TH-B004
Same_Sky_CPG-01-TH-B005
Same_Sky_CPG-01-TH-B006
C_0402_1005Metric004
Same_Sky_CPG-01-TH-B007
Same_Sky_CPG-01-TH-B008
Same_Sky_CPG-01-TH-B009
Same_Sky_CPG-01-TH-B010
Same_Sky_CPG-01-TH-B011
Same_Sky_CPG-01-TH-B012
Same_Sky_CPG-01-TH-B013
C_0402_1005Metric006
Same_Sky_CPG-01-TH-B014
Same_Sky_CPG-01-TH-B015
ecal_simple_solt_copper
ecal_simple_solt_silkscreen
ecal_simple_solt_silkscreen001
ecal_simple_solt_soldermask
ecal_simple_solt_soldermask001
ecal_simple_solt_PCB

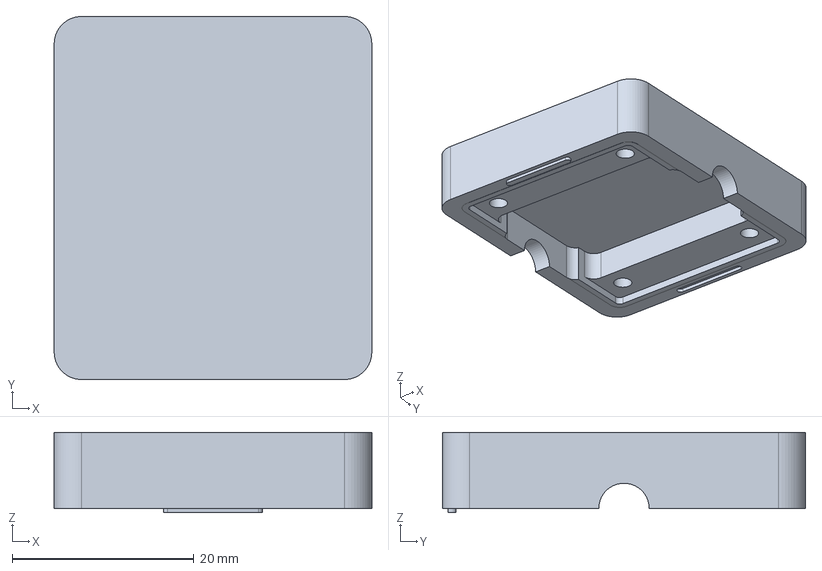
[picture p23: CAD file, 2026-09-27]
CAD/case-top.FCStd
35.0 x 40.0 x 8.82 mm

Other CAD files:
CAD/Assembly.FCStd
CAD/case.FCStd
CAD/case-bottom.FCStd
CAD/PCB.3mf
CAD/assembly-Assemblycase_bottom.3mf
CAD/assembly.FCStd
CAD/scal.3mf

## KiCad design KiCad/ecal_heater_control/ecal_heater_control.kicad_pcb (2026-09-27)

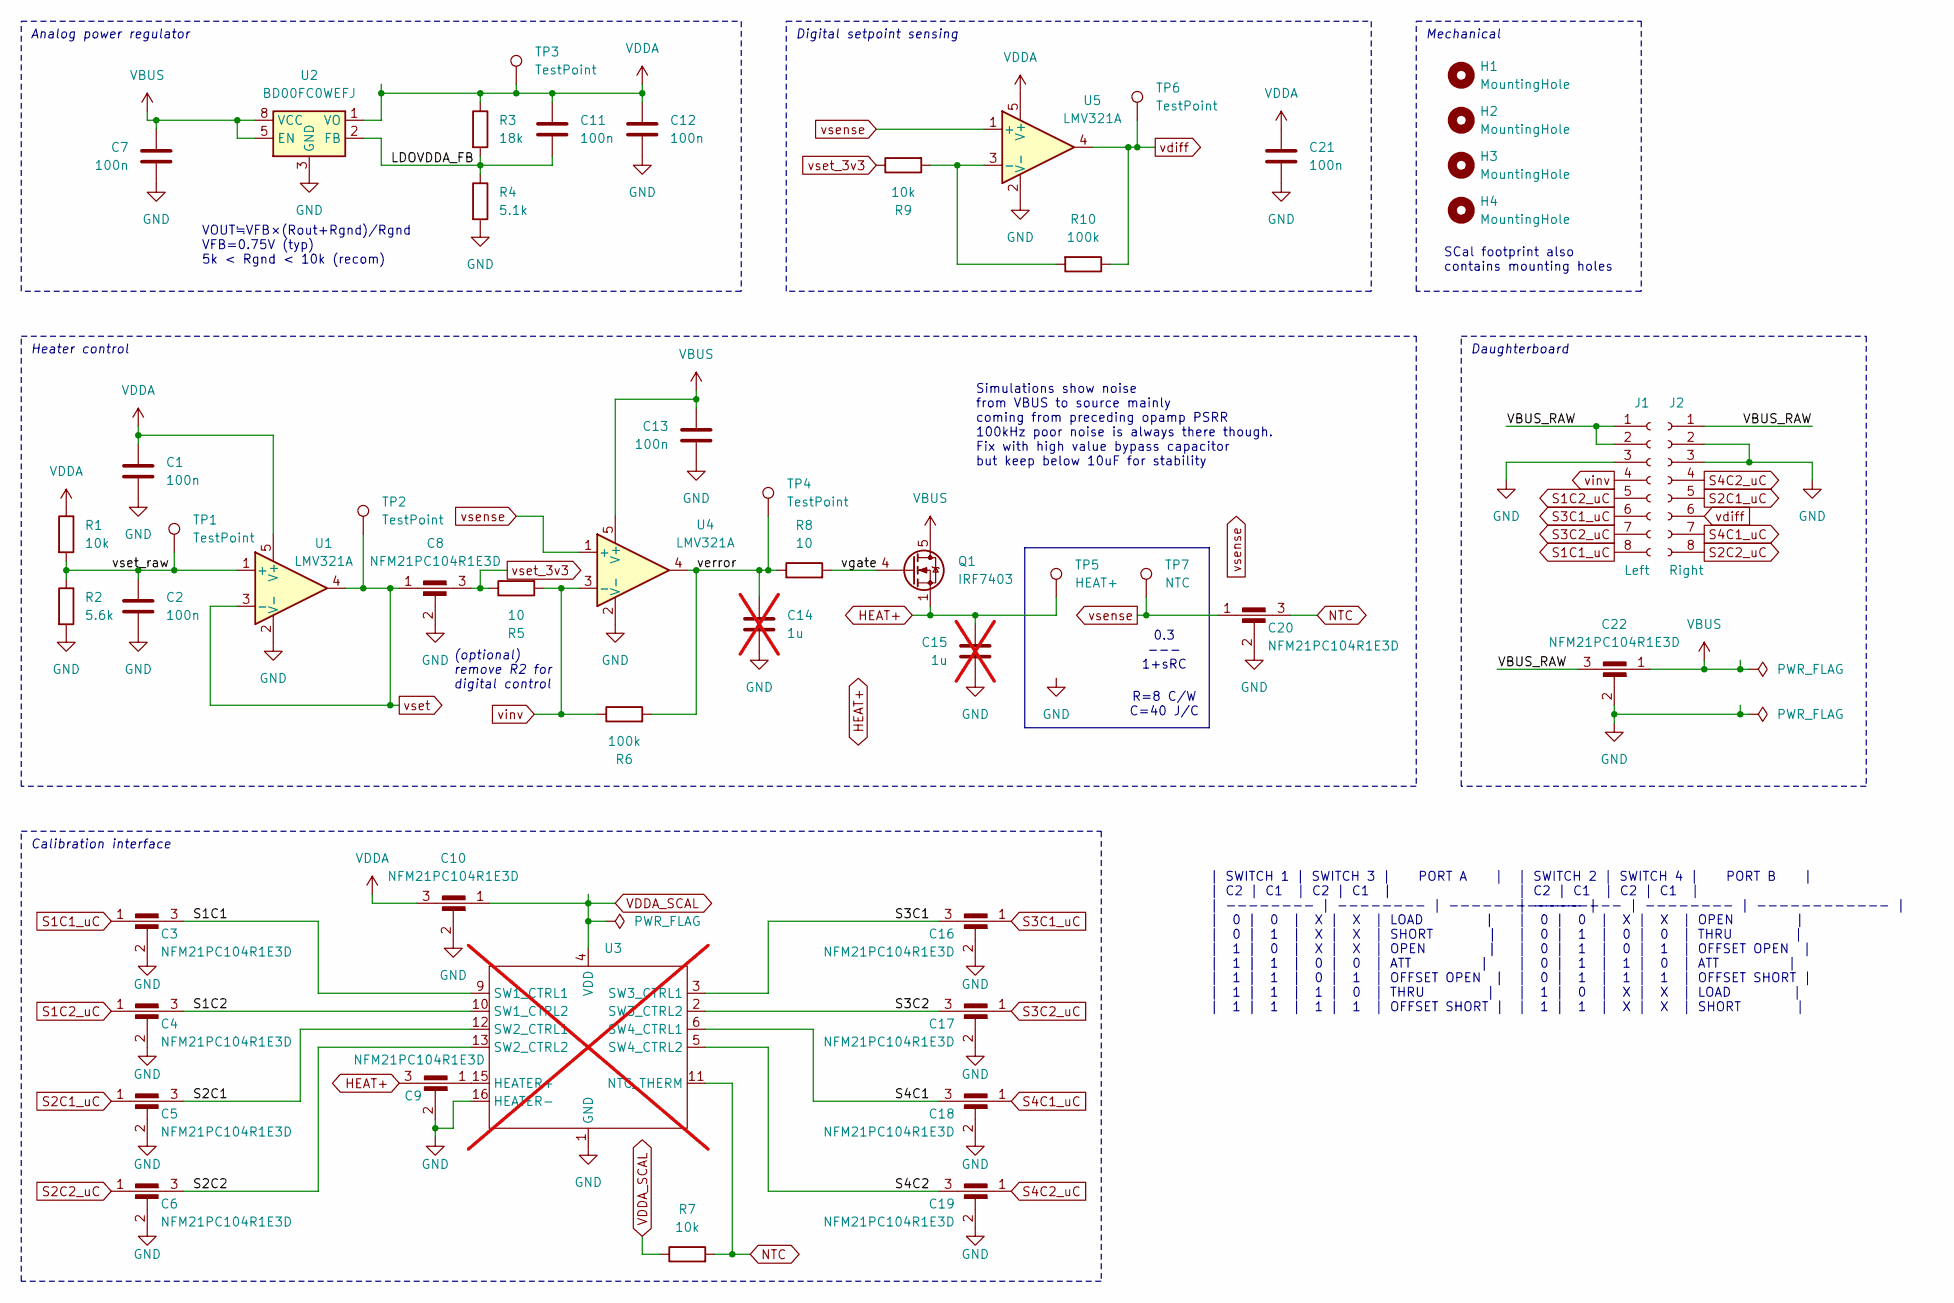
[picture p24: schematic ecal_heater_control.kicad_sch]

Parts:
C1, C2, C7, C11, C12, C13, C21: 100n; C_0402_1005Metric
C3, C4, C5, C6, C8, C9, C10, C16, C17, C18, C19, C20, C22: NFM21PC104R1E3D; NFM21PC
C14, C15: 1u; C_0603_1608Metric; not fitted
H1, H2, H3, H4: MountingHole; MountingHole_3.2mm_M3_DIN965
J1: Left; PinSocket_1x08_P2.54mm_Vertical
J2: Right; PinSocket_1x08_P2.54mm_Vertical
Q1: IRF7403; SOIC-8_3.9x4.9mm_P1.27mm
R1, R7, R9: 10k; R_0402_1005Metric
R2: 5.6k; R_0402_1005Metric
R3: 18k; R_0402_1005Metric
R4: 5.1k; R_0402_1005Metric
R5, R8: 10; R_0402_1005Metric
R6, R10: 100k; R_0402_1005Metric
TP1, TP2, TP3, TP4, TP6: TestPoint; TestPoint_Pad_D1.0mm
TP5: HEAT+; TestPoint_Pad_D1.0mm
TP7: NTC; TestPoint_Pad_D1.0mm
U1, U4, U5: LMV321A; SOT-23-5
U2: BD00FC0WEFJ; HTSOP-8-1EP_3.9x4.9mm_P1.27mm_EP2.4x3.2mm
U3: SCAL; not fitted

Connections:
/LDOVDDA_FB: C11.2, R3.2, R4.1, U2.2 (FB)
/S1C1: C3.3, U3.9 (SW1_CTRL1)
/S1C2: C4.3, U3.10 (SW1_CTRL2)
/S2C1: C5.3, U3.12 (SW2_CTRL1)
/S2C2: C6.3, U3.13 (SW2_CTRL2)
/S3C1: C16.3, U3.3 (SW3_CTRL1)
/S3C2: C17.3, U3.2 (SW3_CTRL2)
/S4C1: C18.3, U3.6 (SW4_CTRL1)
/S4C2: C19.3, U3.5 (SW4_CTRL2)
/VBUS_RAW: C22.3, J1.1, J1.2, J2.1
/verror: C14.1, R6.2, R8.1, TP4.1 (1_1), U4.4
/vgate: Q1.4 (G), R8.2
/vset_raw: C2.1, R1.2, R2.1, TP1.1 (1_1), U1.1 (+)
GND: C1.2, C2.2, C3.2, C4.2, C5.2, C6.2, C7.2, C8.2, C9.2, C10.2, C12.2, C13.2, C14.2, C15.2, C16.2, C17.2, C18.2, C19.2, C20.2, C21.2, C22.2, J1.3, J2.2, J2.3, R2.2, R4.2, U1.2 (V-), U2.3 (GND), U2.9 (GND), U3.1 (GND), U3.7 (GND), U3.8 (GND), U3.14 (GND), U3.16 (HEATER-), U4.2 (V-), U5.2 (V-)
HEAT+: C9.3, C15.1, Q1.1 (S), Q1.2 (S), Q1.3 (S), TP5.1 (1_1)
NTC: C20.3, R7.2, U3.11 (NTC_THERM)
unnamed: C9.1, U3.15 (HEATER+)
unnamed: R9.2, R10.2, U5.3 (-)
S1C1_uC: C3.1, J1.8
S1C2_uC: C4.1, J1.5
S2C1_uC: C5.1, J2.5
S2C2_uC: C6.1, J2.8
S3C1_uC: C16.1, J1.6
S3C2_uC: C17.1, J1.7
S4C1_uC: C18.1, J2.7
S4C2_uC: C19.1, J2.4
VBUS: C7.1, C13.1, C22.1, Q1.5 (D), Q1.6 (D), Q1.7 (D), Q1.8 (D), U2.5 (EN), U2.8 (VCC), U4.5 (V+)
VDDA: C1.1, C10.3, C11.1, C12.1, C21.1, R1.1, R3.1, TP3.1 (1_1), U1.5 (V+), U2.1 (VO), U5.5 (V+)
VDDA_SCAL: C10.1, R7.1, U3.4 (VDD)
vdiff: J2.6, R10.1, TP6.1 (1_1), U5.4
vinv: J1.4, R5.2, R6.1, U4.3 (-)
vsense: C20.1, TP7.1 (1_1), U4.1 (+), U5.1 (+)
vset: C8.1, TP2.1 (1_1), U1.3 (-), U1.4
vset_3v3: C8.3, R5.1, R9.1

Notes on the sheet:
Daughterboard
Digital setpoint sensing
VOUT≒VFB×(Rout+Rgnd)/Rgnd VFB=0.75V (typ) 5k < Rgnd < 10k (recom)
Heater control
0.3 --- 1+sRC
Analog power regulator
SCal footprint also contains mounting holes
Calibration interface
Simulations show noise from VBUS to source mainly coming from preceding opamp PSRR 100kHz poor noise is always there though. Fix with high value bypass capacitor but keep below 10uF for stability
(optional) remove R2 for digital control
R=8 C/W C=40 J/C
Mechanical
| SWITCH 1 | SWITCH 3 | PORT A | | C2 | C1 | C2 | C1 | | -------- | -------- | ------------ | | 0 | 0 | X | X | LOAD | | 0 | 1 | X | X | SHORT | | 1 | 0 | X | X | OPEN | | 1 | 1 | 0 | 0 | ATT | | 1 | 1 | 0 | 1 | OFFSET OPEN | | 1 | 1 | 1 | 0 | THRU | | 1 | 1 | 1 | 1 | OFFSET SHORT |
| SWITCH 2 | SWITCH 4 | PORT B | | C2 | C1 | C2 | C1 | | -------- | -------- | ------------ | | 0 | 0 | X | X | OPEN | | 0 | 1 | 0 | 0 | THRU | | 0 | 1 | 0 | 1 | OFFSET OPEN | | 0 | 1 | 1 | 0 | ATT | | 0 | 1 | 1 | 1 | OFFSET SHORT | | 1 | 0 | X | X | LOAD | | 1 | 1 | X | X | SHORT |

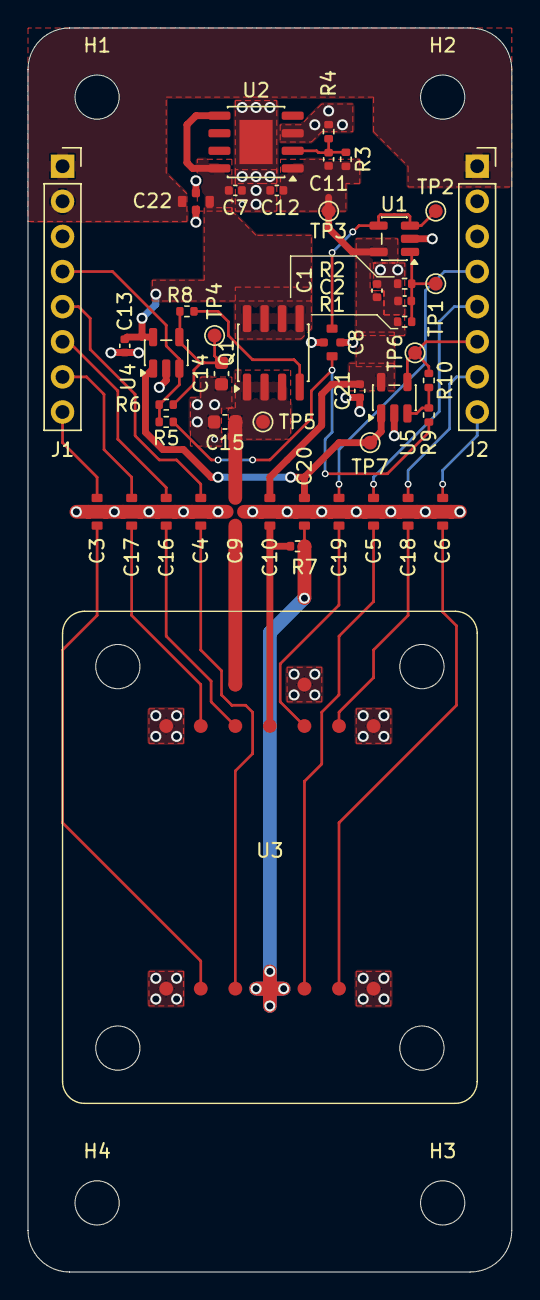
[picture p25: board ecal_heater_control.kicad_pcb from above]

Board: 2 copper layers, 35.0 x 90.0 mm, 51 parts (0 on the bottom side), 34 nets.

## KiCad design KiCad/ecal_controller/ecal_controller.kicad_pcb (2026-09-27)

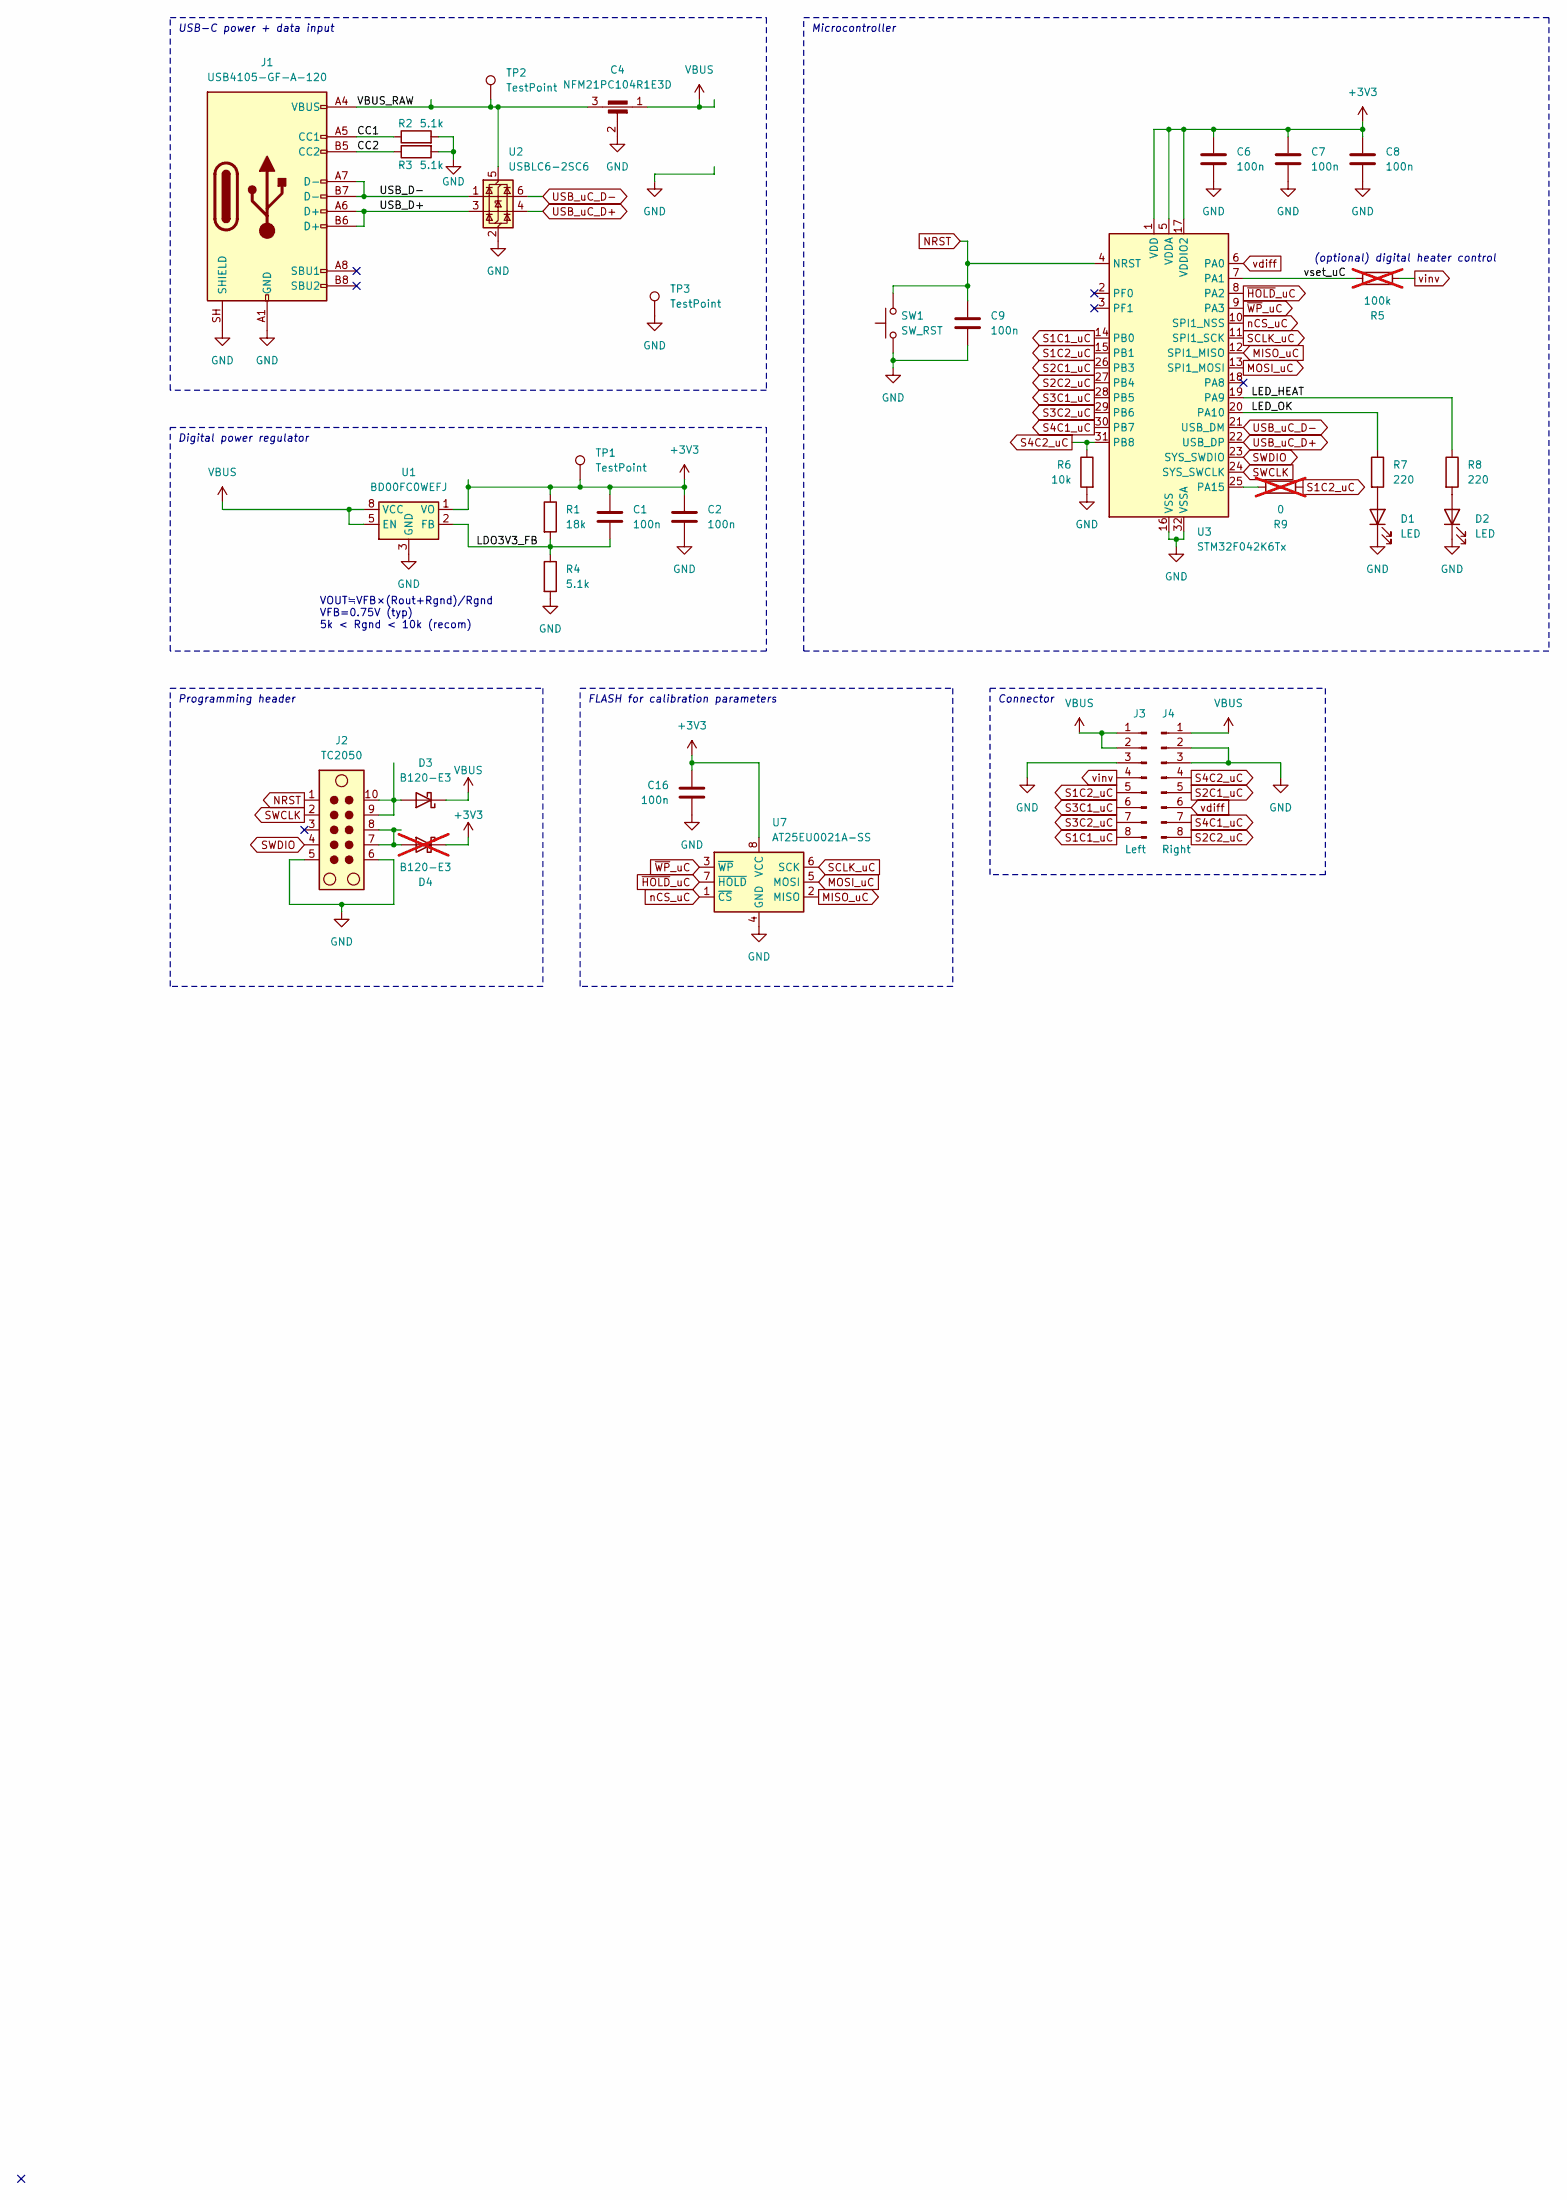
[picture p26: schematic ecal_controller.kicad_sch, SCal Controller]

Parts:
C1, C2, C6, C7, C8, C9, C16: 100n; C_0402_1005Metric
C4: NFM21PC104R1E3D; NFM21PC
D1, D2: LED; LED_0603_1608Metric
D3: B120-E3; D_SMA
D4: B120-E3; D_SMA; not fitted
J1: USB4105-GF-A-120; USB_C_Receptacle_GCT_USB4110
J2: TC2050; Tag-Connect_TC2050-IDC-FP_2x05_P1.27mm_Vertical
J3: Left; PinHeader_1x08_P2.54mm_Vertical
J4: Right; PinHeader_1x08_P2.54mm_Vertical
R1: 18k; R_0402_1005Metric
R2, R3, R4: 5.1k; R_0402_1005Metric
R5: 100k; R_0402_1005Metric; not fitted
R6: 10k; R_0402_1005Metric
R7, R8: 220; R_0402_1005Metric
R9: 0; R_0402_1005Metric; not fitted
SW1: SW_RST; SW_Push_1P1T_NO_E-Switch_TL3301NxxxxxG
TP1, TP2, TP3: TestPoint; TestPoint_Pad_D1.0mm
U1: BD00FC0WEFJ; HTSOP-8-1EP_3.9x4.9mm_P1.27mm_EP2.4x3.2mm
U2: USBLC6-2SC6; SOT-23-6
U3: STM32F042K6Tx; LQFP-32_7x7mm_P0.8mm
U7: AT25EU0021A-SS; SOIC-8_3.9x4.9mm_P1.27mm

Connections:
+3V3: C1.1, C2.1, C6.1, C7.1, C8.1, C16.1, D4.1 (K), R1.1, TP1.1 (1_1), U1.1 (VO), U3.1 (VDD), U3.5 (VDDA), U3.17 (VDDIO2), U7.8 (VCC)
/CC1: J1.A5 (CC1), R2.1
/CC2: J1.B5 (CC2), R3.1
/LDO3V3_FB: C1.2, R1.2, R4.1, U1.2 (FB)
/LED_HEAT: R8.1, U3.19 (PA9)
/LED_OK: R7.1, U3.20 (PA10)
/USB_D+: J1.A6 (D+), J1.B6 (D+), U2.3 (I/O2)
/USB_D-: J1.A7 (D-), J1.B7 (D-), U2.1 (I/O1)
/VBUS_RAW: C4.3, J1.A4 (VBUS), J1.A9 (VBUS), J1.B4 (VBUS), J1.B9 (VBUS), TP2.1 (1_1), U2.5 (VBUS)
/vset_uC: R5.1, U3.7 (PA1)
GND: C2.2, C4.2, C6.2, C7.2, C8.2, C9.2, C16.2, D1.1 (K), D2.1 (K), J1.A1 (GND), J1.A12 (GND), J1.B1 (GND), J1.B12 (GND), J1.SH (SHIELD), J2.5, J2.6, J3.3, J4.2, J4.3, R2.2, R3.2, R4.2, R6.2, SW1.1, TP3.1 (1_1), U1.3 (GND), U1.9 (GND), U2.2 (GND), U3.16 (VSS), U3.32 (VSSA), U7.4 (GND)
MISO_uC: U3.12 (SPI1_MISO), U7.2 (MISO)
MOSI_uC: U3.13 (SPI1_MOSI), U7.5 (MOSI)
NRST: C9.1, J2.1, SW1.2, U3.4 (NRST)
unnamed: D1.2 (A), R7.2
unnamed: D2.2 (A), R8.2
unnamed: D3.2 (A), J2.9, J2.10
unnamed: D4.2 (A), J2.7, J2.8
unnamed: R9.1, U3.25 (PA15)
S1C1_uC: J3.8, U3.14 (PB0)
S1C2_uC: J3.5, R9.2, U3.15 (PB1)
S2C1_uC: J4.5, U3.26 (PB3)
S2C2_uC: J4.8, U3.27 (PB4)
S3C1_uC: J3.6, U3.28 (PB5)
S3C2_uC: J3.7, U3.29 (PB6)
S4C1_uC: J4.7, U3.30 (PB7)
S4C2_uC: J4.4, R6.1, U3.31 (PB8)
SCLK_uC: U3.11 (SPI1_SCK), U7.6 (SCK)
SWCLK: J2.2, U3.24 (SYS_SWCLK)
SWDIO: J2.4, U3.23 (SYS_SWDIO)
USB_uC_D+: U2.4 (I/O2), U3.22 (USB_DP)
USB_uC_D-: U2.6 (I/O1), U3.21 (USB_DM)
VBUS: C4.1, D3.1 (K), J3.1, J3.2, J4.1, U1.5 (EN), U1.8 (VCC)
nCS_uC: U3.10 (SPI1_NSS), U7.1 (~CS)
vdiff: J4.6, U3.6 (PA0)
vinv: J3.4, R5.2
~HOLD_uC: U3.8 (PA2), U7.7 (~HOLD)
~WP_uC: U3.9 (PA3), U7.3 (~WP)

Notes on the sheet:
Digital power regulator
VOUT≒VFB×(Rout+Rgnd)/Rgnd VFB=0.75V (typ) 5k < Rgnd < 10k (recom)
USB-C power + data input
Programming header
FLASH for calibration parameters
Connector
(optional) digital heater control
Microcontroller

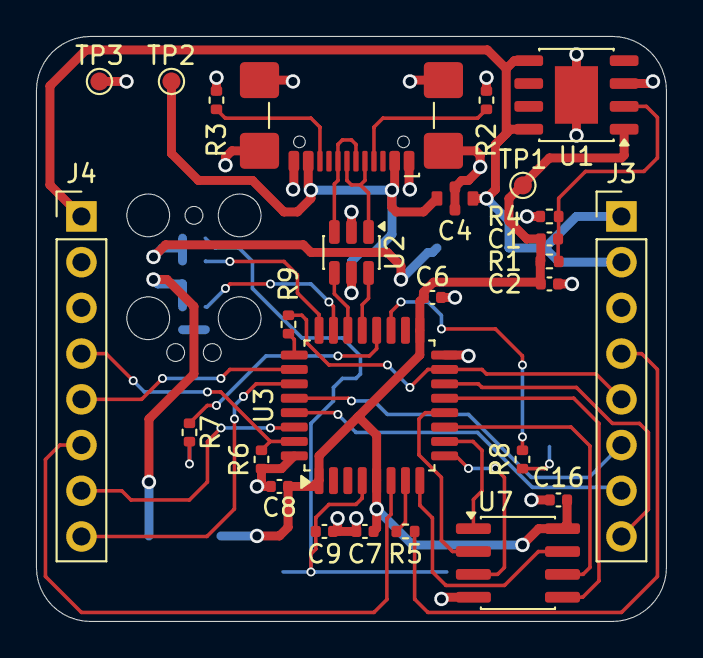
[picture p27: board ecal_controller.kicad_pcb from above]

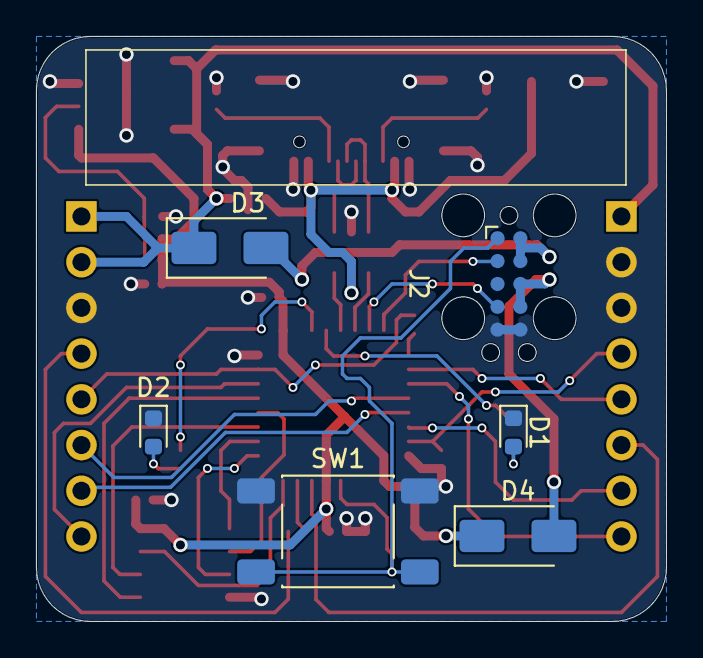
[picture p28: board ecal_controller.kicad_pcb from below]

Board: 2 copper layers, 35.0 x 32.5 mm, 33 parts (6 on the bottom side), 38 nets.

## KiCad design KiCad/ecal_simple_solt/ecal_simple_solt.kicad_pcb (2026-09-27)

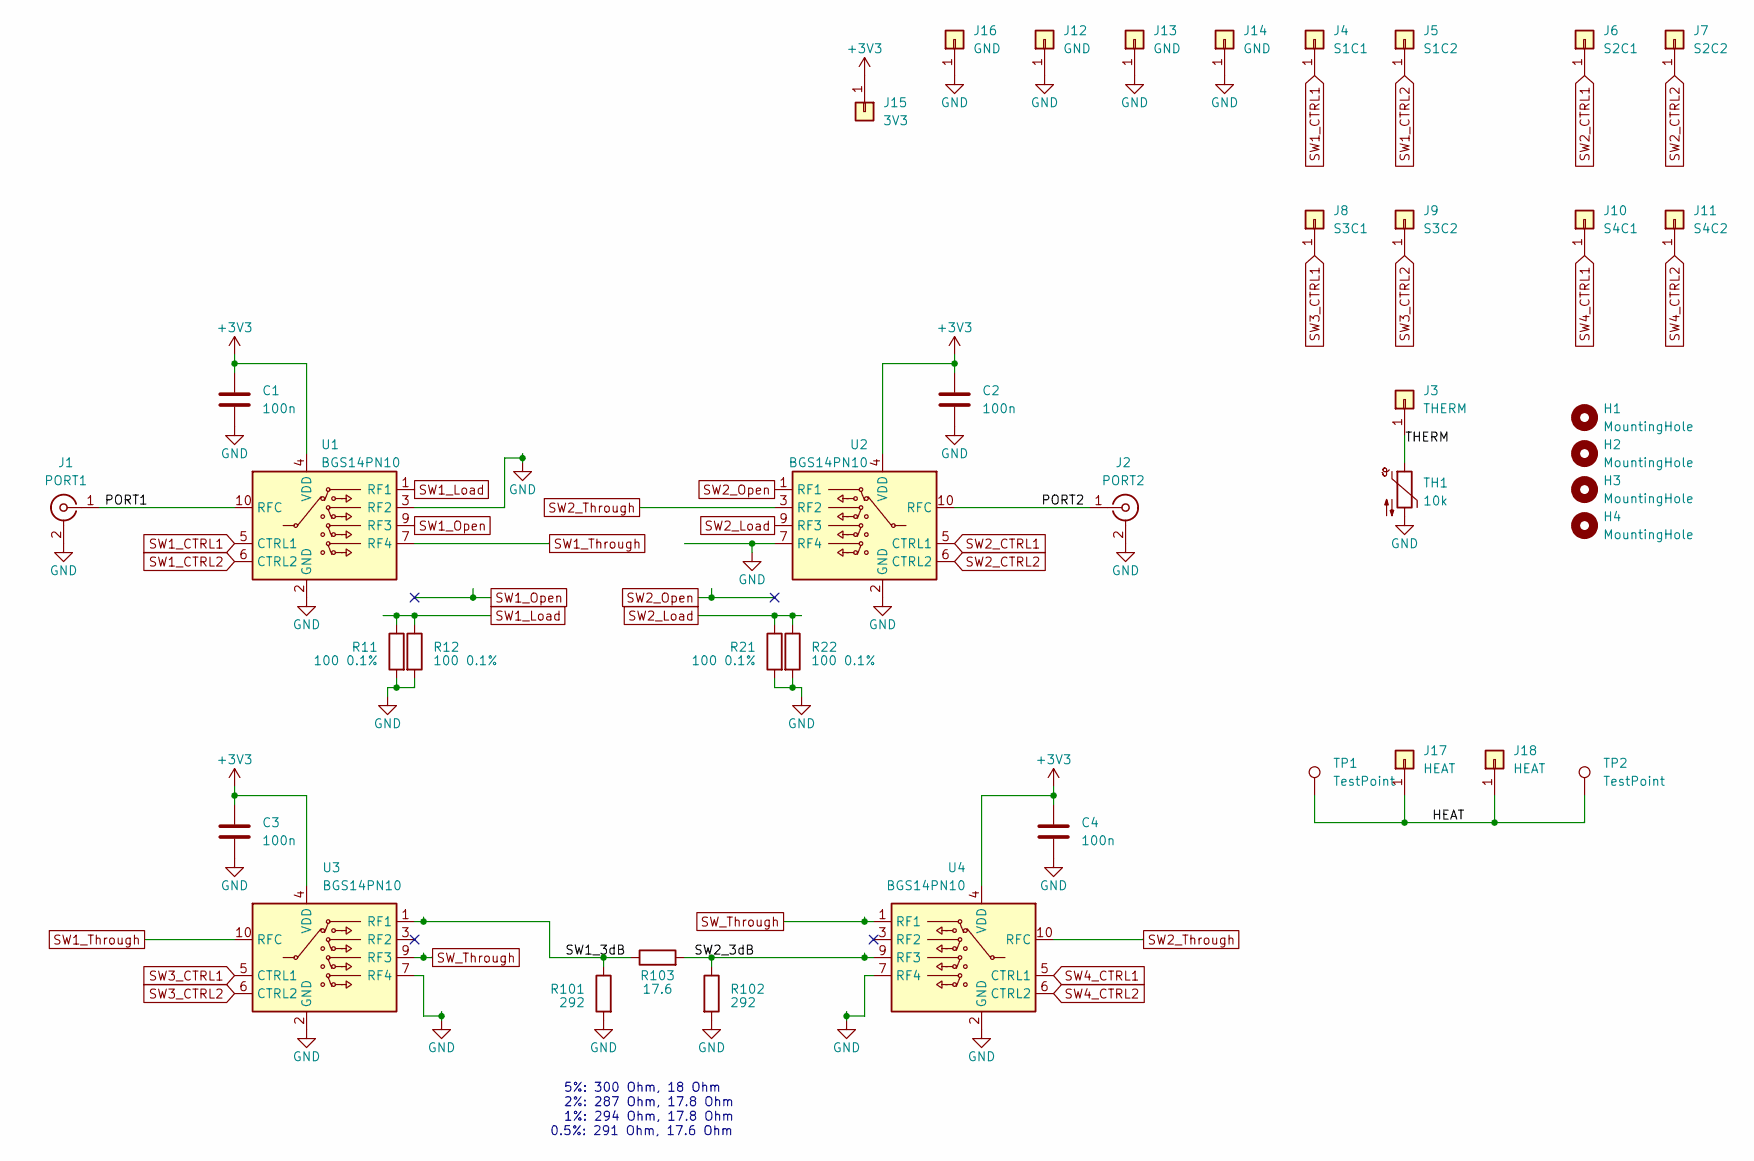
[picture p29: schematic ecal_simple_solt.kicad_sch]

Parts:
C1, C2, C3, C4: 100n; C_0402_1005Metric
H1, H2, H3, H4: MountingHole; MountingHole_3.2mm_M3_ISO7380
J1: PORT1; 32K243-40ML5; MPN 32K243-40ML5; Mouser No 476-32K243-40ML5
J2: PORT2; 32K243-40ML5; MPN 32K243-40ML5; Mouser No 476-32K243-40ML5
J3: THERM; CPG-01-TH-B; MPN CPG-01-TH-B
J4: S1C1; CPG-01-TH-B; MPN CPG-01-TH-B
J5: S1C2; CPG-01-TH-B; MPN CPG-01-TH-B
J6: S2C1; CPG-01-TH-B; MPN CPG-01-TH-B
J7: S2C2; CPG-01-TH-B; MPN CPG-01-TH-B
J8: S3C1; CPG-01-TH-B; MPN CPG-01-TH-B
J9: S3C2; CPG-01-TH-B; MPN CPG-01-TH-B
J10: S4C1; CPG-01-TH-B; MPN CPG-01-TH-B
J11: S4C2; CPG-01-TH-B; MPN CPG-01-TH-B
J12, J13, J14, J16: GND; CPG-01-TH-B; MPN CPG-01-TH-B
J15: 3V3; CPG-01-TH-B; MPN CPG-01-TH-B
J17, J18: HEAT; CPG-01-TH-B; MPN CPG-01-TH-B
R11, R12, R21, R22: 100 0.1%; R_0201_0603Metric
R101, R102: 292; R_0402_1005Metric
R103: 17.6; R_0402_1005Metric
TH1: 10k; R_0402_1005Metric; MPN NCU15XH103D60RC; Mouser No 81-NCU15XH103D60RC
TP1, TP2: TestPoint; TestPoint_Pad_1.0x1.0mm
U1, U2, U3, U4: BGS14PN10; XQFP-10; MPN BGS14PN10E6327XTSA1; Mouser No 726-BGS14PN10E6327X

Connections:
+3V3: C1.1, C2.1, C3.1, C4.1, J15.1 (Pin_1_1), U1.4 (VDD), U2.4 (VDD), U3.4 (VDD), U4.4 (VDD)
/HEAT: J17.1 (Pin_1_1), J18.1 (Pin_1_1), TP1.1 (1_1), TP2.1 (1_1)
/PORT1: J1.1 (In), U1.10 (RFC)
/PORT2: J2.1 (In), U2.10 (RFC)
/SW1_3dB: R101.1, R103.1, U3.1 (RF1)
/SW2_3dB: R102.1, R103.2, U4.9 (RF3)
/THERM: J3.1 (Pin_1_1), TH1.1
GND: C1.2, C2.2, C3.2, C4.2, J1.2 (Ext), J2.2 (Ext), J12.1 (Pin_1_1), J13.1 (Pin_1_1), J14.1 (Pin_1_1), J16.1 (Pin_1_1), R11.2, R12.2, R21.2, R22.2, R101.2, R102.2, TH1.2, U1.2 (GND), U1.3 (RF2), U1.8 (GND), U2.2 (GND), U2.7 (RF4), U2.8 (GND), U3.2 (GND), U3.7 (RF4), U3.8 (GND), U4.2 (GND), U4.7 (RF4), U4.8 (GND)
SW1_CTRL1: J4.1 (Pin_1_1), U1.5 (CTRL1)
SW1_CTRL2: J5.1 (Pin_1_1), U1.6 (CTRL2)
SW1_Load: R11.1, R12.1, U1.1 (RF1)
SW1_Open: U1.9 (RF3)
SW1_Through: U1.7 (RF4), U3.10 (RFC)
SW2_CTRL1: J6.1 (Pin_1_1), U2.5 (CTRL1)
SW2_CTRL2: J7.1 (Pin_1_1), U2.6 (CTRL2)
SW2_Load: R21.1, R22.1, U2.9 (RF3)
SW2_Open: U2.1 (RF1)
SW2_Through: U2.3 (RF2), U4.10 (RFC)
SW3_CTRL1: J8.1 (Pin_1_1), U3.5 (CTRL1)
SW3_CTRL2: J9.1 (Pin_1_1), U3.6 (CTRL2)
SW4_CTRL1: J10.1 (Pin_1_1), U4.5 (CTRL1)
SW4_CTRL2: J11.1 (Pin_1_1), U4.6 (CTRL2)
SW_Through: U3.9 (RF3), U4.1 (RF1)

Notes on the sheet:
5%: 300 Ohm, 18 Ohm 2%: 287 Ohm, 17.8 Ohm 1%: 294 Ohm, 17.8 Ohm 0.5%: 291 Ohm, 17.6 Ohm

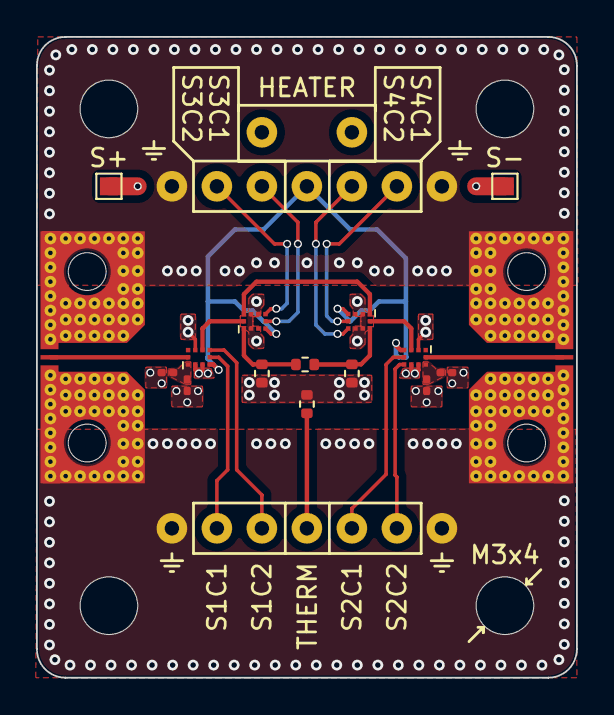
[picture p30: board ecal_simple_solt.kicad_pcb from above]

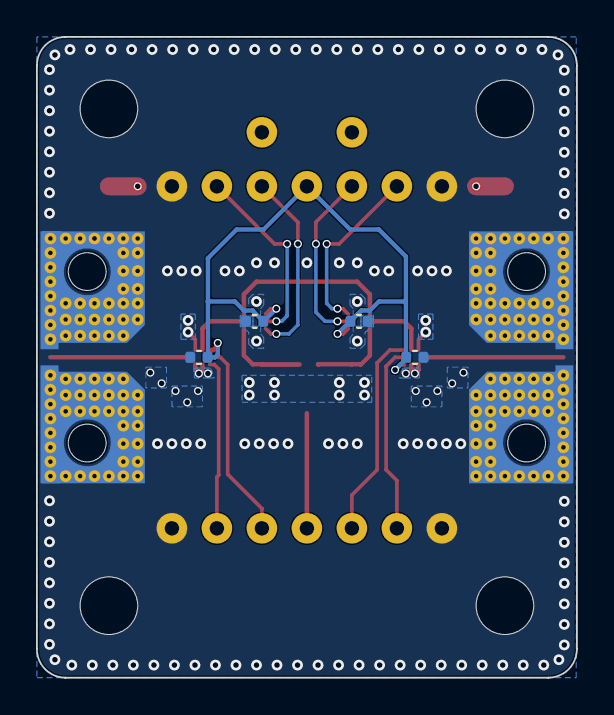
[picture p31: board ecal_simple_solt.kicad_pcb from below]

Board: 4 copper layers, 30.0 x 35.6 mm, 40 parts (20 on the bottom side), 21 nets.

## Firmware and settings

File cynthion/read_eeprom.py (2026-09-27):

#!/usr/bin/env python3

import argparse
import usb.core
import usb.util
import sys
from typing import cast


def find_ecal_device() -> usb.core.Device | None:
    """Find the USB ECal device with vendor ID 0x0957 and product ID 0x0001."""
    # device = usb.core.find(idVendor=0x0957, idProduct=0x0001)
    # device = usb.core.find(idVendor=0x2A8D, idProduct=0x3F01)
    device = usb.core.find(
        custom_match=lambda d: (d.idVendor == 0x0957 and d.idProduct == 0x0001)
        or (d.idVendor == 0x2A8D and d.idProduct == 0x3F01)
    )
    if device is None:
        print("USB ECal device not found. Please ensure it's connected.")
        return None

    print(f"Found device: {device}")
    return cast(usb.core.Device, device)


def set_eeprom_address(device: usb.core.Device, address: int) -> bool:
    """Set the EEPROM address using vendor request #4.

    For addresses > 0xFFFF, the upper 16 bits go in wValue and lower 16 bits in wIndex.
    """
    try:
        # Split 32-bit address into upper and lower 16-bit parts
        address_low = address & 0xFFFF  # Lower 16 bits
        address_high = (address >> 16) & 0xFFFF  # Upper 16 bits

        # Vendor request #4: OUT direction
        result = device.ctrl_transfer(
            bmRequestType=0x41,  # Vendor request, host to device
            bRequest=4,  # Vendor request number 4
            wValue=address_high,  # Upper 16 bits of address
            wIndex=address_low,  # Lower 16 bits of address
            data_or_wLength=0,  # No data payload
        )
        return True
    except usb.core.USBError as e:
        print(f"Error setting EEPROM address 0x{address:08X}: {e}")
        return False


def set_bytes_to_read(device: usb.core.Device, num_bytes: int) -> bool:
    """Set the number of bytes to read using vendor request #2.

    Limited to 16 bits (max 65535 bytes).
    """
    try:
        # Ensure we don't exceed 16-bit limit
        if num_bytes > 0xFFFF:
            print(
                f"Warning: Requested bytes ({num_bytes}) exceeds 16-bit limit, clamping to 65535"
            )
            num_bytes = 0xFFFF

        # Vendor request #2: OUT direction, set byte count in wValue
        result = device.ctrl_transfer(
            bmRequestType=0x41,  # Vendor request, host to device
            bRequest=2,  # Vendor request number 2
            wValue=num_bytes,  # Number of bytes to read (max 0xFFFF)
            wIndex=0,  # Not used for byte count
            data_or_wLength=0,  # No data payload
        )
        return True
    except usb.core.USBError as e:
        print(f"Error setting bytes to read: {e}")
        return False


def set_state(device: usb.core.Device, state: int) -> bool:
    """Set the state using vendor request #1."""
    try:
        # Vendor request #1: OUT direction, set state in wValue
        result = device.ctrl_transfer(
            bmRequestType=0x41,  # Vendor request, host to device
            bRequest=1,  # Vendor request number 1
            wValue=state,  # State to set
            wIndex=0,  # Not used
            data_or_wLength=0,  # No data payload
        )
        return True
    except usb.core.USBError as e:
        print(f"Error setting state: {e}")
        return False


def read_eeprom_chunk(
    device: usb.core.Device, address: int, chunk_size: int
) -> bytes | None:
    """Read a single chunk of EEPROM data at the specified address.

    Handles 16-bit limitations of USB control transfers.
    """
    try:
        # Ensure chunk size doesn't exceed 16-bit limit
        if chunk_size > 0xFFFF:
            print(
                f"Warning: Chunk size {chunk_size} exceeds 16-bit limit, clamping to 65535"
            )
            chunk_size = 0xFFFF

        # Set EEPROM address for this chunk
        if not set_eeprom_address(device, address):
            return None

        # Set number of bytes to read for this chunk
        if not set_bytes_to_read(device, chunk_size):
            return None

        # Read the chunk data
        data = bytearray()
        bytes_remaining = chunk_size
        packet_size = 64  # Max packet size

        while bytes_remaining > 0:
            # Read up to packet_size bytes at a time
            bytes_to_read = min(packet_size, bytes_remaining)
            try:
                chunk = device.read(0x81, bytes_to_read, timeout=1000)
                data.extend(chunk)
                bytes_remaining -= len(chunk)

                # If we got less than requested, we might be at the end
                if len(chunk) < bytes_to_read:
                    break

            except (usb.core.USBTimeoutError, usb.core.USBError) as e:
                if "Operation timed out" in str(e) or isinstance(
                    e, usb.core.USBTimeoutError
                ):
                    # Timeout likely means we've reached the end of valid data
                    break
                else:
                    raise

        return bytes(data)
    except usb.core.USBError as e:
        print(f"Error reading EEPROM chunk at address 0x{address:08X}: {e}")
        return None


def read_eeprom_chunked(
    max_size: int = 262 * 1024, chunk_size: int = 512
) -> bytes | None:
    """Read EEPROM data in chunks, making separate requests for each chunk."""
    device = find_ecal_device()
    if device is None:
        return None

    try:
        # Detach kernel driver if necessary
        if device.is_kernel_driver_active(0):
            device.detach_kernel_driver(0)

        # Set configuration
        device.set_configuration()

        all_data = bytearray()
        current_address = 0
        expected_address = 0  # Track expected next address for gap detection
        chunk_count = 0
        consecutive_empty_chunks = 0
        max_empty_chunks = 5  # Stop after 5 consecutive empty/failed chunks

        print(f"Reading EEPROM in {chunk_size}-byte chunks...")

        while (
            len(all_data) < max_size
            and consecutive_empty_chunks < max_empty_chunks
        ):
            # Calculate how much we still need to read
            bytes_remaining = max_size - len(all_data)
            current_chunk_size = min(chunk_size, bytes_remaining)

            # Check for address gap (assert no gaps are present)
            if chunk_count > 0:  # Skip check for first chunk
                assert current_address == expected_address, (
                    f"Address gap detected! Expected address 0x{expected_address:08X}, "
                    f"but current address is 0x{current_address:08X}. "
                    f"Gap of {current_address - expected_address} bytes found."
                )

            # Read this chunk
            chunk_data = read_eeprom_chunk(
                device, current_address, current_chunk_size
            )

            if chunk_data is None or len(chunk_data) == 0:
                consecutive_empty_chunks += 1
                current_address += current_chunk_size
                expected_address = current_address  # Update expected address even for failed chunks
                continue

            # Reset empty chunk counter if we got data
            consecutive_empty_chunks = 0

            # Only take the data we need (in case we got more than requested)
            needed_bytes = min(len(chunk_data), bytes_remaining)
            all_data.extend(chunk_data[:needed_bytes])
            chunk_count += 1

            # Progress indicator every 16 chunks
            if chunk_count % 16 == 0:
                print(
                    f"Progress: Read {chunk_count} chunks, {len(all_data)} bytes total (address: 0x{current_address:08X})"
                )

            current_address += current_chunk_size
            expected_address = current_address  # Update expected next address

        print(
            f"\nRead completed: {len(all_data)} bytes total from {chunk_count} successful chunks"
        )
        return bytes(all_data)

    except usb.core.USBError as e:
        print(f"USB error: {e}")
        return None
    finally:
        # Release the device
        usb.util.dispose_resources(device)


def main() -> None:
    """Main function to demonstrate EEPROM reading."""
    parser = argparse.ArgumentParser(
        description="Read EEPROM data from Agilent USB ECal Module"
    )
    parser.add_argument(
        "-o",
        "--output",
        type=str,
        default="eeprom_dump.bin",
        help="Output filename for the EEPROM data (default: eeprom_dump.bin)",
    )
    parser.add_argument(
        "-s",
        "--size",
        type=str,
        default="64k",
        help="Total size to read (e.g., 64k, 1M, 4M). Default: 64k",
    )

    args = parser.parse_args()

    # Parse size argument
    size_str = args.size.lower()
    if size_str.endswith("k"):
        total_size = int(size_str[:-1]) * 1024
    elif size_str.endswith("m"):
        total_size = int(size_str[:-1]) * 1024 * 1024
    else:
        total_size = int(size_str)

    # Automatically determine optimal chunk size that doesn't exceed 0xFFFF
    # Use 4KB chunks for efficiency while staying well under the 64KB limit
    chunk_size = min(4 * 1024, 0xFFFF, total_size)  # 4KB or smaller

    print(f"Reading {total_size // 1024} KB total in {chunk_size}-byte chunks")
    if total_size > 0xFFFF:
        print(
            "Note: Using extended addressing (wValue for upper 16 bits) for addresses > 65535"
        )
    print(
        "Will stop automatically when device stops responding or at end of data"
    )

    data = read_eeprom_chunked(total_size, chunk_size)

    if data:
        print(f"Successfully read {len(data)} bytes:")
        # Print first 256 bytes as hex dump for verification
        print("First 256 bytes:")
        for i in range(0, min(256, len(data)), 16):
            hex_part = " ".join(f"{b:02x}" for b in data[i : i + 16])
            ascii_part = "".join(
                chr(b) if 32 <= b < 127 else "." for b in data[i : i + 16]
            )
            print(f"{i:04x}: {hex_part:<48} {ascii_part}")

        if len(data) > 256:
            print(f"... ({len(data) - 256} more bytes)")

        # Save to specified output file
        with open(args.output, "wb") as f:
            f.write(data)
        print(f"Data saved to {args.output}")
    else:
        print("Failed to read EEPROM data")
        sys.exit(1)


if __name__ == "__main__":
    main()

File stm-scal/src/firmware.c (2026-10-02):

#include "common.h"
#include "spi_flash.h"
#include "usb.h"

#include <libopencm3/cm3/systick.h>
#include <libopencm3/stm32/crs.h>
#include <libopencm3/stm32/gpio.h>
#include <libopencm3/stm32/rcc.h>

#define LED_RCC (RCC_GPIOA)
#define LED_PORT (GPIOA)
#define LED_RED (GPIO9)
#define LED_GREEN (GPIO10)

#define SYSTICK_FREQ (1000)

volatile uint64_t ticks = 0;

void sys_tick_handler(void) {
    ticks++;
}

static uint64_t get_ticks(void) {
    return ticks;
}

static void rcc_setup(void) {
    /* Crystal-less: HSI48 for core and USB, trimmed to the USB SOF by the CRS */
    rcc_clock_setup_in_hsi48_out_48mhz();
    rcc_set_usbclk_source(RCC_HSI48);
    crs_autotrim_usb_enable();
}

static void gpio_setup(void) {
    rcc_periph_clock_enable(LED_RCC);
    gpio_mode_setup(LED_PORT, GPIO_MODE_OUTPUT, GPIO_PUPD_NONE, LED_RED | LED_GREEN);
}

static void systick_setup(void) {
    systick_set_frequency(SYSTICK_FREQ, rcc_ahb_frequency);
    systick_counter_enable();
    systick_interrupt_enable();
}

static bool flash_test(void) {
    uint8_t id[3];
    spi_flash_read_id(id);

    return id[0] == 0x1f;
}

int main(void) {
    rcc_setup();
    gpio_setup();

    systick_setup();

    spi_flash_setup();
    const uint16_t led = flash_test() ? LED_GREEN : LED_RED;

    usb_setup();

    uint64_t start_time = get_ticks();

    /* Infinte loop */
    for (;;) {
        usb_poll();

        if (get_ticks() - start_time >= 500) {
            gpio_toggle(LED_PORT, led);
            start_time = get_ticks();
        }
    }

    // Never return
    return 0;
}

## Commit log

2023-07-07 Add PCB
    [ecal_simple_solt.kicad_pcb, ecal_simple_solt.kicad_sch]
2026-07-22 New revision
    [ecal_simple_solt.kicad_pcb, ecal_simple_solt.kicad_sch]
2026-07-23 Optimize for casing
    [ecal_simple_solt.kicad_pcb, ecal_simple_solt.step]
2026-07-24 Better directory structure
    [ecal_controller.kicad_pcb, ecal_controller.kicad_sch, ecal_simple_solt.kicad_pcb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]
2026-09-27 Bit of an overdue commit
    [Assembly.FCStd, NFM21PC104R1E3D.stp, PCB.3mf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]
2026-09-27 Add initial USB endpoints with Nucleo development board
2026-10-02 Fix toolchain and read flash (blink green for success, red for fail)
    [firmware.c, spi_flash.c]
2026-10-02 Some PCB files
